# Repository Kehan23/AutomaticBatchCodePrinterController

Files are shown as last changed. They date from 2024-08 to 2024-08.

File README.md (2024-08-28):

# Automatic Batch Code Printer Controller

This repository contains the design and implementation details for the Automatic Batch Code Printer, developed as part of the EN2160 - Electronic Design Realization course at the University of Moratuwa. The project leverages ATmega microcontrollers, shift registers, and other electronic components to achieve precise and reliable printing on various surfaces.

## Table of Contents
- [Introduction](#introduction)
- [Schematics](#schematics)
- [PCB Design and Assembly](#pcb-design-and-assembly)
- [Enclosure Design](#enclosure-design)
- [Detailed Programming Information](#detailed-programming-information)
- [Daily Log Entries](#daily-log-entries)
- [Getting Started](#getting-started)
- [Contributors](#contributors)

## Introduction

The Automatic Batch Code Printer is designed to generate and print batch codes on multiple surfaces with high precision. It integrates several ATmega microcontrollers that handle tasks such as bit pattern generation, signal processing, pressure control, and surface detection, ensuring high-quality and efficient printing.
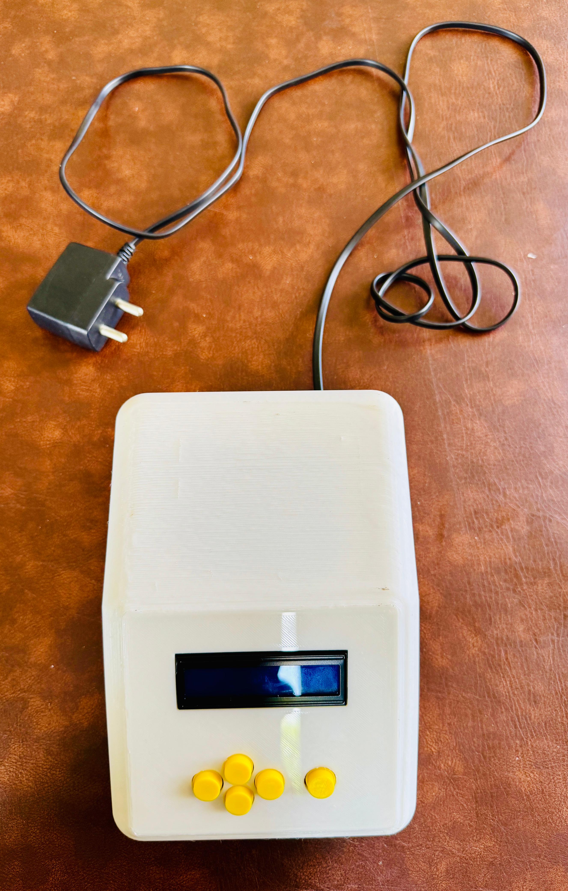
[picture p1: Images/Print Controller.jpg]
Print Controller


### Key Features
- **High Precision Printing**: Utilizes piezoelectric technology and PWM signals for fine control over ink droplet formation.
- **Versatility**: Capable of printing on various surfaces with real-time adjustments for optimal print conditions.
- **Robust and Reliable**: Features fail-safe mechanisms for pressure control and surface detection to prevent printing errors.
- **Efficient and Environmentally Friendly**: Lower energy consumption and minimal ink wastage compared to traditional printing methods.

## Schematics

Detailed schematics for the entire system, including the main and secondary microcontrollers, power supply, shift registers, and pressure control circuits, are provided. These schematics are crucial for understanding the layout and connections between components.
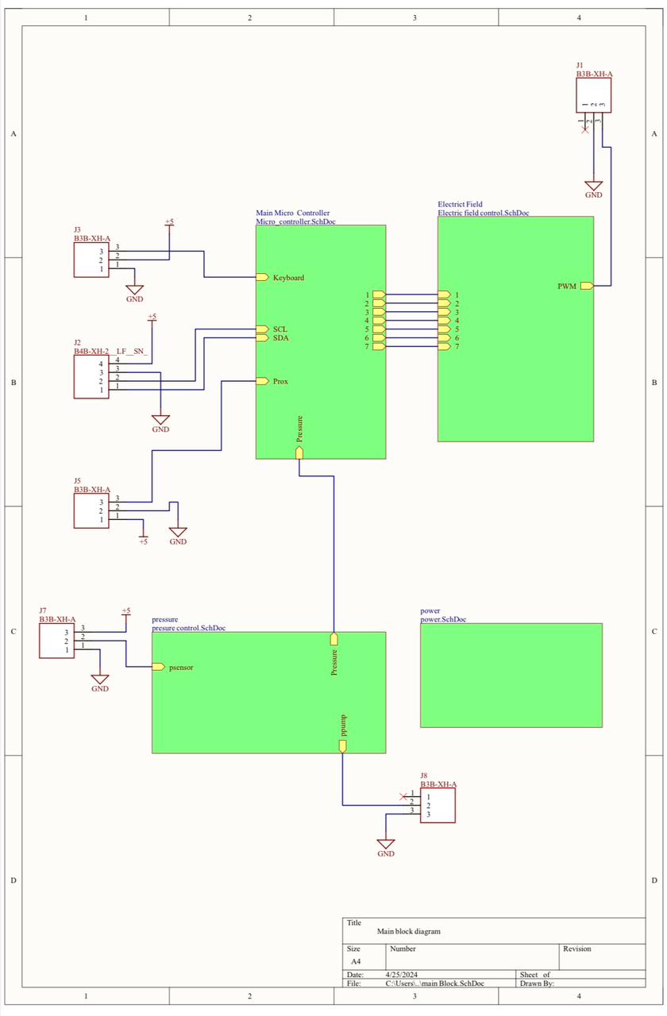
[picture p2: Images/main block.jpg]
Hierarchical Design

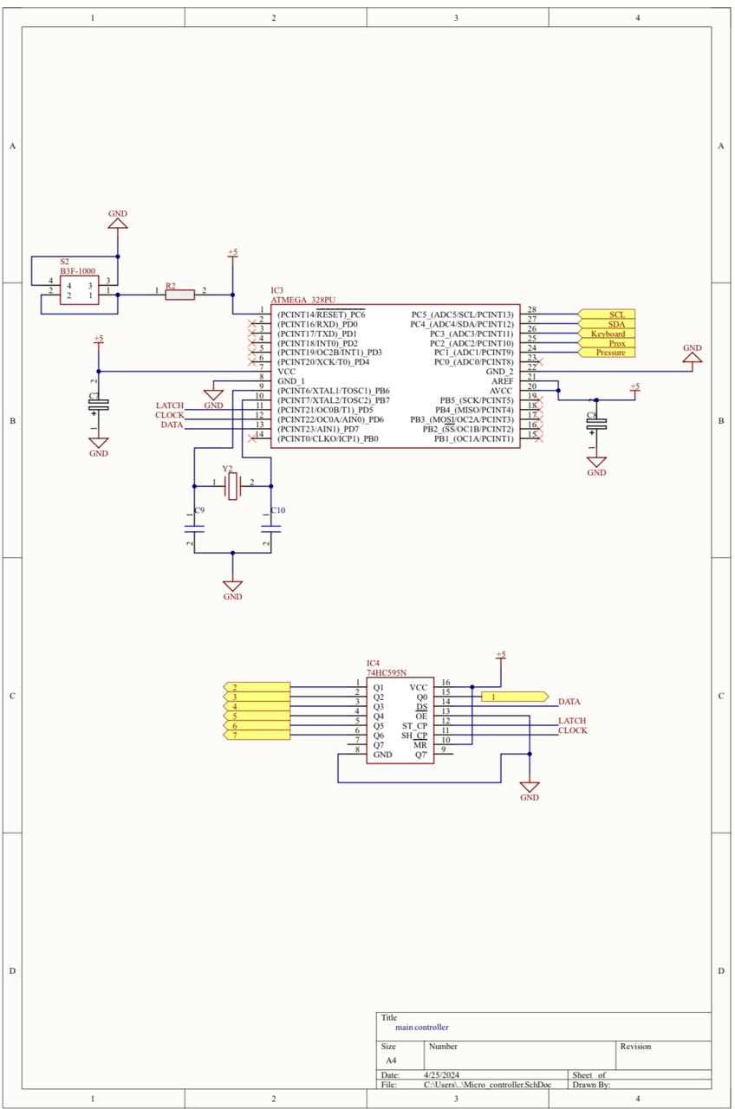
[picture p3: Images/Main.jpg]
Main Circuit

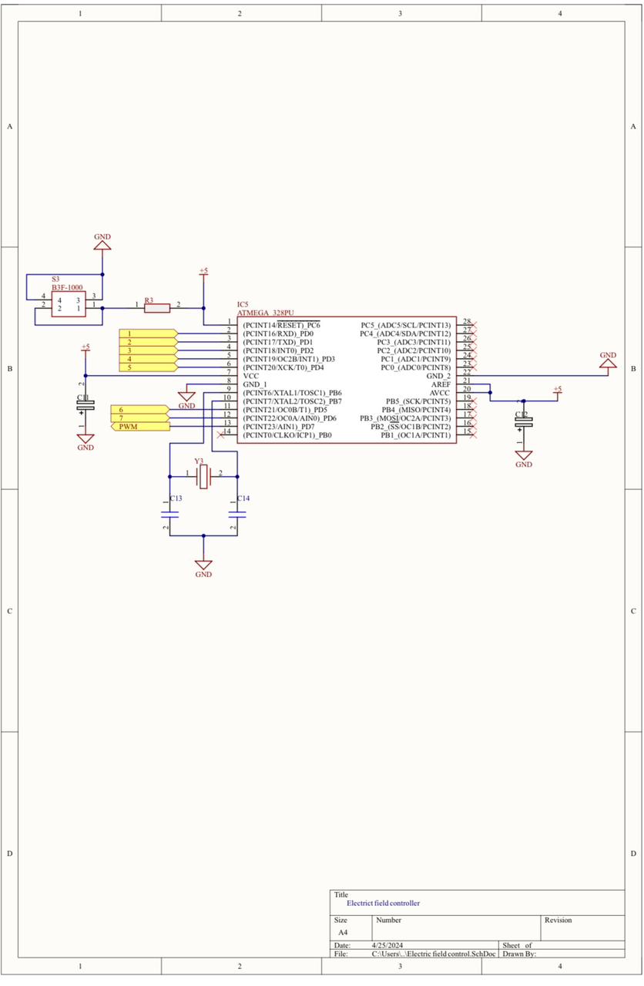
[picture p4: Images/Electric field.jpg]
Electric Field

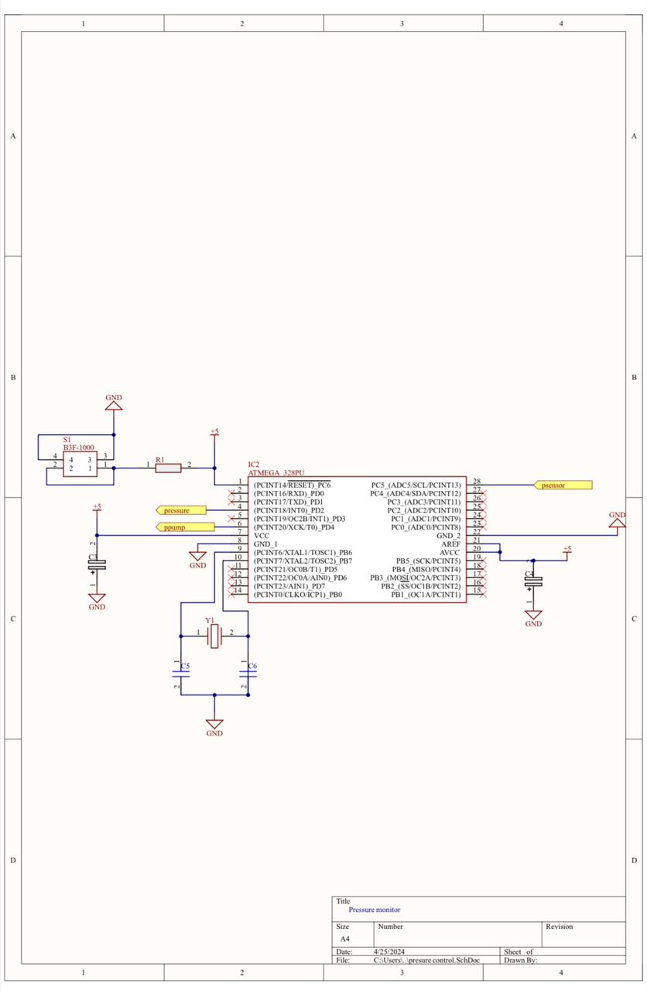
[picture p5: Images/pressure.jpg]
Pressure Controll Design


## PCB Design and Assembly

### PCB Design
The PCB design for this project was meticulously crafted to ensure signal integrity, power management, and minimal interference. The design process included optimal component placement, routing, and adherence to industry standards.
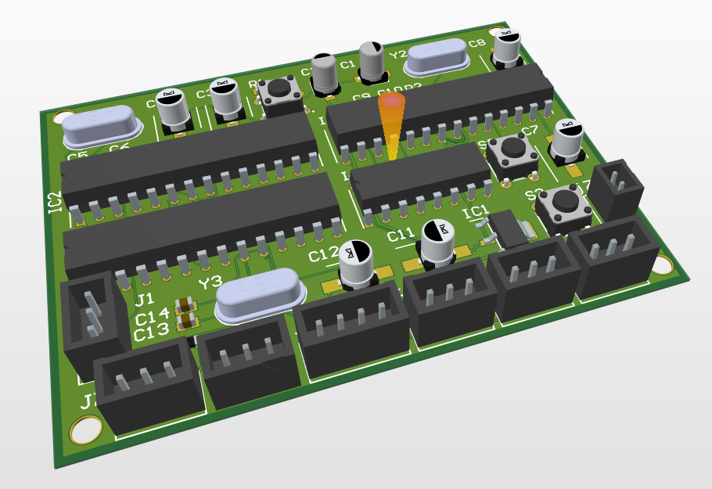
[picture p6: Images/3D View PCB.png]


### PCB Assembly
Photographs of both the bare and soldered PCBs are included, along with evidence of PCB testing to ensure functionality before final assembly.
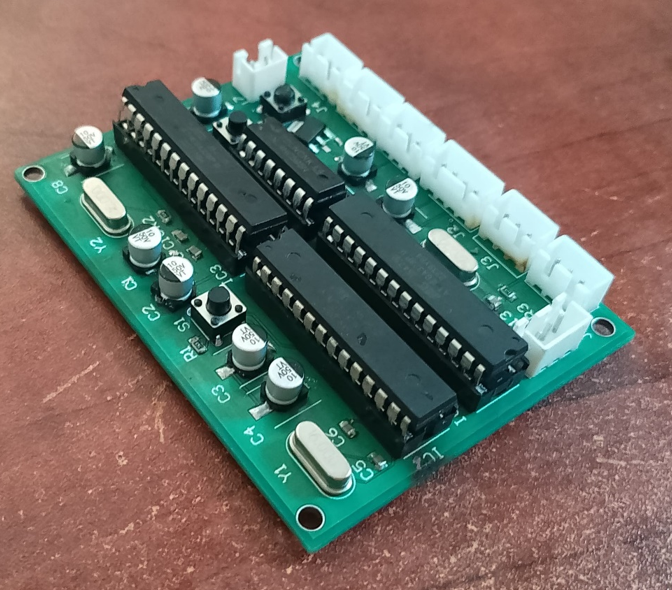
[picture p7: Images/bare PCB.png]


## Enclosure Design

The project also includes a custom-designed enclosure for the batch code printer. The enclosure is designed to house all the critical components securely while providing easy access for maintenance. Detailed design drawings and photographs of the assembled enclosure are available.
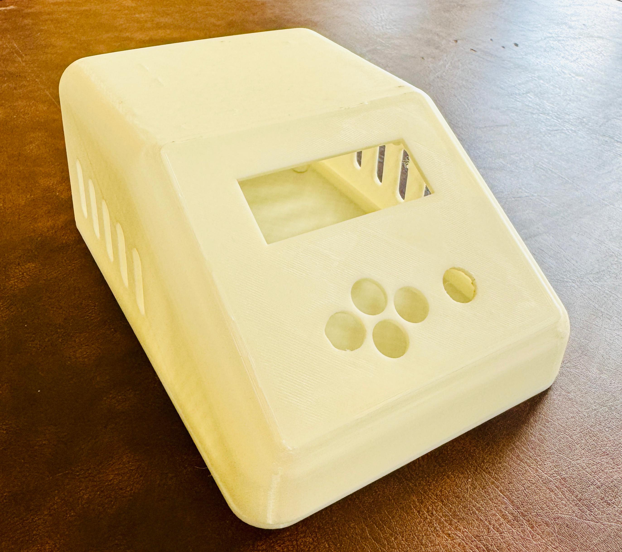
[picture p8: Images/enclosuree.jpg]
Enclosure


## Detailed Programming Information

The programming section includes the full source code used to control the printer, handle user inputs, and manage the printing process. This code is essential for replicating the functionality of the system and includes:
- ASCII to bitmap conversion for dot matrix printing.
- PWM signal generation for controlling the print head.
- Proximity sensor integration for accurate surface detection.
- Pressure monitoring and control algorithms.

## Daily Log Entries

A detailed log of the project development process is provided, documenting each stage from initial concept to final implementation. This includes design reviews, component selection, circuit design, programming, PCB layout, and enclosure fabrication.

## Getting Started

### Prerequisites
- **Arduino IDE**: Required for compiling and uploading the provided code to the microcontrollers.
- **Microchip Studio**: Used for programming the ATmega microcontrollers.

### Instructions
1. **Hardware Setup**: Assemble the circuit and connect all components as per the provided schematics and PCB layout.
2. **Software Upload**: Use the Arduino IDE to upload the code to the microcontrollers.
3. **Operation**: Power up the system, input the desired batch code using the provided keyboard interface, and initiate the printing process.

## Contributors

- **Anjula M.K** 
- **Meemanage N.A**
  
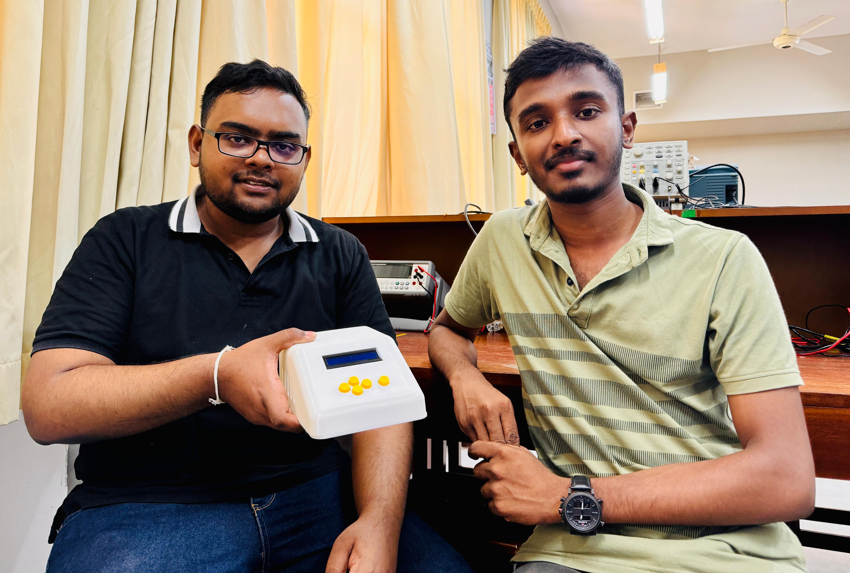
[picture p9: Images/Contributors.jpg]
Group


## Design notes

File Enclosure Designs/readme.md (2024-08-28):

# Enclosure Designs for Print Controller

## Top Part of the Enclosure
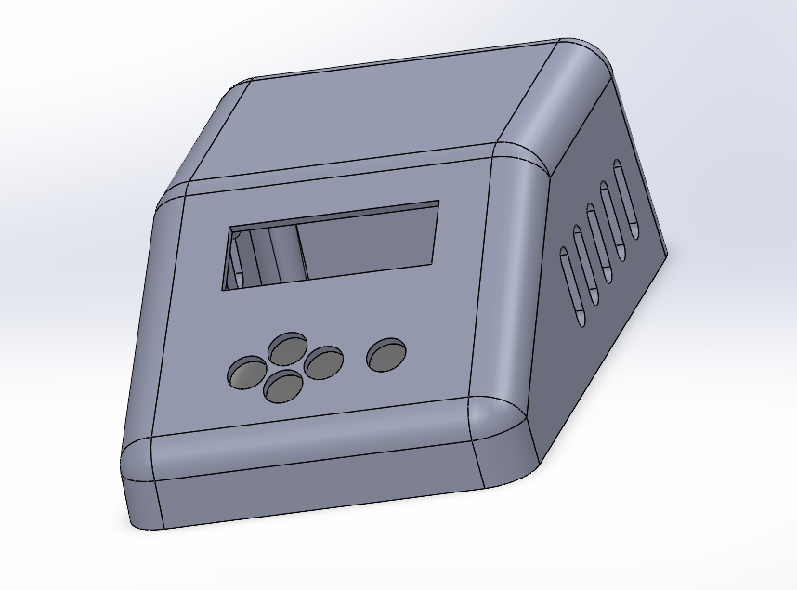
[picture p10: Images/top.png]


## Base of the Enclosure
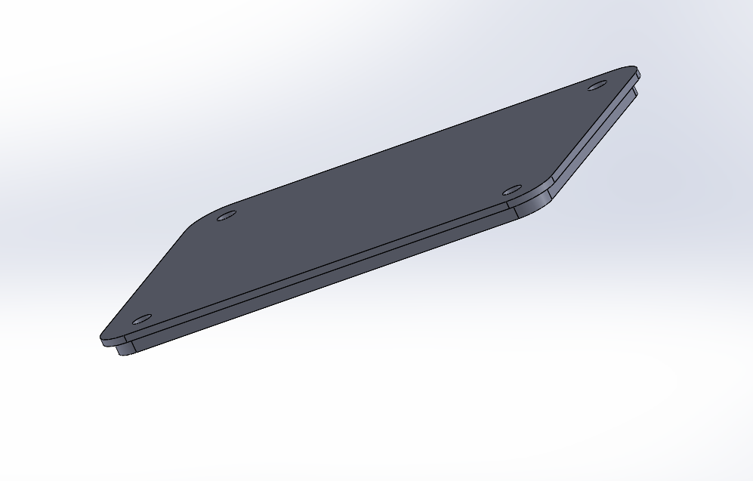
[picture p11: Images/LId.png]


## Printed Enclosure
Printed Enclosure

## Assembly of the Enclosure
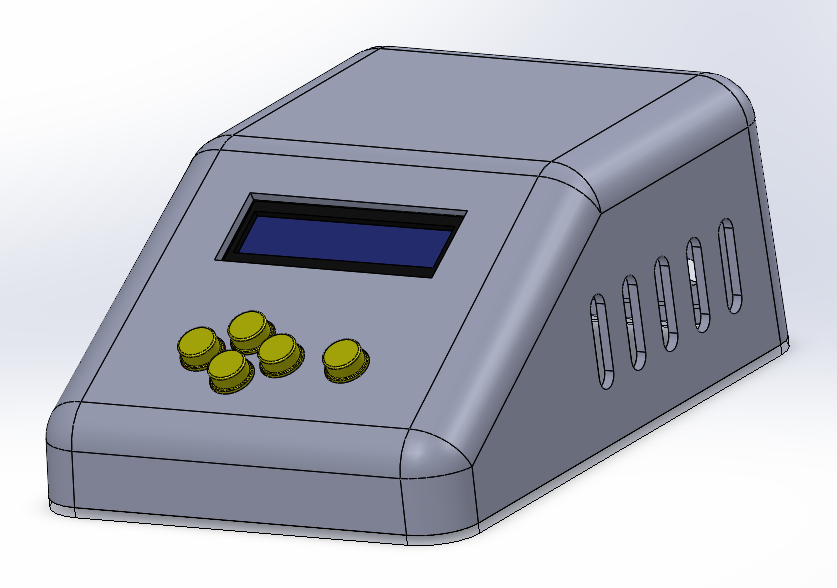
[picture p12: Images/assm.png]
Assembly


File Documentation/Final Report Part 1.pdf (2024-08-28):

## Department of Electronic and Telecommunication Engineering

## University of Moratuwa

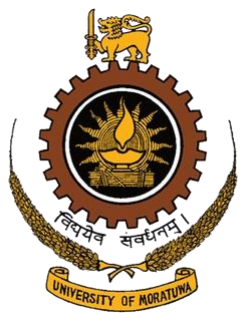
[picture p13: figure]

## EN2160 - Electronic Design Realization Automatic Batch Code Printer

Design Methodology Report

Anjula M.K | 210368V
Meemanage N.A | 210385U

Table of Contents

## 1.Introduction

In today’s fast-paced industrial environment, the ability to efficiently and accurately label products with essential information such as manufacturing dates, expiry dates, and batch numbers is crucial. Automatic batch coding technologies have emerged as a vital component in various sectors, including pharmaceuticals, food and beverage, cosmetics, and electronics. These technologies enhance traceability, compliance, and quality control, ensuring that consumers receive reliable and safe products.

The advancements in automatic batch coding devices, particularly those utilizing inkjet printing technology, represent a significant leap forward in the industry. Inkjet printing technology stands out due to its versatility, speed, and precision, making it an ideal choice for high-volume production environments. This technology can print on a wide range of surfaces and materials, including glass, metal, plastic, and paper, which adds to its applicability across different industries.

Leading companies and universities are at the forefront of innovating and refining these technologies. Their research and development efforts focus on improving the efficiency, accuracy, and environmental sustainability of inkjet printing systems. Innovations include the development of high-resolution printers, the integration of smart technology for real-time monitoring and adjustments, and the use of environmentally friendly inks that reduce the carbon footprint of the printing process.

This report aims to provide a comprehensive overview of the current state of automatic batch coding devices using inkjet printing technology. It will cover the progress made in the field, plan the next steps for future advancements, and map the stakeholders involved in these developments. Additionally, it will observe user requirements, stimulate ideas for further innovation, and present conceptual designs and functional block diagrams. The evaluation criteria for selecting the best solutions, along with detailed considerations for ink and ink tube selection, will also be discussed. Finally, the report will delve into the schematics of selected conceptual designs, PCB design and 3D views, and enclosure design, providing a holistic view of the development and implementation of these cutting-edge technologies.

By examining these aspects, the report seeks to highlight the importance of automatic batch coding technologies and their role in enhancing industrial productivity and product safety. Through collaboration between industry leaders and academic institutions, continuous improvements can be achieved, paving the way for more advanced and sustainable batch coding solutions.

2.Review Progress: Project- Automatic Batch Code printer.

Automatic Batch Code Printing Technologies So far.

Introduction: Automatic batch coding technologies play a crucial role in various industries by enabling efficient and accurate labeling of products with essential information such as manufacturing dates, expiry dates, and batch numbers. This report aims to provide an overview of the advancements and innovations in automatic batch coding devices utilizing inkjet printing technology, with a focus on solutions offered by leading companies and universities.

1. Hitachi Inkjet Printing Solutions: Hitachi offers a range of ink formulations and dynamic models for batch coding applications. Their ink formulations allow codes to adhere to various forms of primary packaging, including paper, PP, PET, HDPE, glass, and metal. Hitachi's dynamic models, such as the UX2, UX Basic Model, UX Dynamic Model, and Twin Nozzle Cartridge Model, provide versatility and reliability in batch coding operations. Additionally, the Hitachi Batch Code Ink Jet Printer PXR-D460W offers mobility and compact design, making it suitable for diverse production environments.
2. Domino Printing Sciences: Domino Printing Sciences provides a comprehensive range of batch coding solutions, including manual, semi-automatic, and automatic systems. Their manual batch coding solutions are suitable for small-scale production runs, while semi-automatic solutions offer electronic-driven operation for larger batches. Domino's automatic batch coding machines integrate seamlessly into production lines, applying codes without operator intervention. The company offers both contact and non-contact batch coding machines, utilizing technologies such as thermal transfer overprinting (TTO), continuous inkjet printing (CIJ), and thermal inkjet printing (TIJ).
3. Linx Printing Technologies: Linx specializes in batch coding technologies designed for high-speed printing onto various types of packaging. Their lot number printers ensure clear and durable batch codes for traceability and compliance with regulatory requirements. Linx's automatic coding machines offer ease of setup and operation, with user-friendly interfaces and smartphone-style touchscreen controls. Their continuous inkjet printer, the Linx 8900, is suitable for harsh production environments with its ingress protection (IP) rating.
4. Research and Innovations: Universities and research institutions have also contributed to advancements in automatic batch coding technologies. Research projects focus on improving printing accuracy, speed, and versatility while exploring novel ink formulations and printing methods.

Below is a short, summarized report regarding a research paper published in Linkedin.com

This research paper explores various aspects of batch coding technology, focusing on the importance, types, operation, and application of batch coding machines, particularly in the context of inkjet printing. The paper emphasizes the significance of high-quality batch coding in ensuring product traceability, compliance with regulations, and brand reputation in industries such as FMCG, pharmaceuticals, and automotive.

Key Findings:

1. Importance of Batch Coding: Batch codes play a crucial role in product traceability, allowing manufacturers to track products throughout the supply chain and facilitate efficient recalls if necessary. They contain vital information about manufacturing dates, expiry dates, and other relevant details.
2. Types of Batch Coding Machines: The paper identifies three main types of batch coding machines: manual handheld, semi-automatic, and automatic. Each type caters to different production needs, with automatic systems being the preferred choice for large-scale manufacturing.
3. Technology Overview: Various technologies are available for batch coding, including thermal transfer overprinting (TTO), thermal inkjet (TIJ), continuous inkjet (CIJ), laser marking, and large character marking (LCM). Each technology offers distinct advantages in terms of printing quality, speed, and suitability for different substrates.
4. Operation of Inkjet Batch Coding Machines: Inkjet batch coding machines are user-friendly and offer flexibility in customization. Operators can easily set up the machines to print alphanumeric characters, barcodes, and other information according to specific requirements.
5. Application Examples: The paper provides insights into the application of batch coding machines in different packaging formats, such as plastic bags, bottles, jars, and cartons. It highlights the importance of selecting the appropriate coding technology based on packaging features and production line requirements.

## 3.Plan Next Steps

After outlining the objectives and methodology for the development of an automatic batch coding system utilizing inkjet printing technology, the next crucial step is to plan the subsequent actions to ensure the successful execution of the project. This report presents a comprehensive plan for the next steps based on the outlined project proposal.

### 1. Review Project Scope and Objectives

- Conduct a thorough review of the project scope and objectives to ensure alignment with stakeholders' expectations and industry requirements.
- Verify that all necessary components and functionalities are adequately addressed in the project plan.

### 2. Establish Timeline and Milestones

- Develop a detailed timeline with specific milestones for each phase of the project, including design, fabrication, programming, testing, documentation, and support.
- Assign responsibilities to team members and establish deadlines for each milestone to maintain accountability and track progress effectively.

### 3. Procurement and Material Acquisition:

- Identify and procure all necessary materials, components, and equipment required for the fabrication of the custom print head, microcontroller programming, enclosure construction, and ink selection.
- Ensure that materials meet quality standards and specifications outlined in the project requirements.

### 4. Design and Fabrication of Print Head

- Initiate the design and fabrication process for the custom print head, considering factors such as nozzle size, heating element placement, and ink delivery mechanisms.
- Conduct prototype testing to validate design specifications and functionality before proceeding to full-scale fabrication.

### 5. Microcontroller Programming

- Begin the development of control algorithms and software to interface with the print head and manage printing operations.
- Program the ATmega328P microcontroller to receive batch information from the user interface and command the print head accordingly.

### 6. Enclosure Design and Construction:

- Commence the design phase for the enclosure, ensuring compatibility with the system components and providing accessibility for maintenance.
- Fabricate the enclosure using appropriate materials and assembly techniques to ensure protection and ease of use.

### 7. Integration and Testing:

- Assemble the system components within the enclosure and perform rigorous testing to validate functionality, reliability, and print quality.
- Iterate on design and software as necessary based on testing results to optimize performance and address any identified issues.

### 8. Documentation and Support:

- Create comprehensive documentation, including assembly instructions, operating procedures, and troubleshooting guidelines, concurrently with system development.
- Provide ongoing support and assistance to users for successful implementation and operation of the automatic batch coding system.

### 9. Stakeholder Communication and Feedback:

- Maintain regular communication with stakeholders to provide updates on project progress, address any concerns or feedback, and ensure alignment with expectations.
- Solicit feedback from stakeholders throughout the project lifecycle to incorporate any necessary adjustments or refinements

## 4.Stake Holder Mapping

The list of stakeholders that are related to our project is given below.

1. Project Team Members:
2. Project Supervisor
3. End-Users/ Customers
4. Regulatory Bodies (Government)
5. Industry Associations (Packaging and manufacturing industry)
6. Financial Stakeholders
7. Marketing and Sales
8. Environmental and Sustainability Groups:
9. Community
10. Competitors (Competing companies in the same industry)
11. Research and Development
12. Media (News outlets covering advancements in manufacturing or technology)

## 5.Observe Users

1. User Interface Preferences:
- Users expressed a preference for a simple and intuitive user interface that allows for easy input of batch information.
- Clear and legible display screens were highlighted as important for readability in busy production environments.
2. Print Head Interaction:
- Operators emphasized the importance of a reliable and durable print head that requires minimal maintenance.
- Ease of access to the print head for cleaning and replacement of ink cartridges was identified as a key consideration.
3. Enclosure Design:
- Observations revealed a need for an enclosure that provides adequate protection for the internal components while allowing for easy access during maintenance and troubleshooting.
4. Documentation and Support:
- Stakeholders highlighted the importance of comprehensive documentation and support materials to assist with assembly, operation, and troubleshooting of the automatic batch coding system.
- User training programs and ongoing technical support were identified as essential for successful implementation and operation of the system.

## 6.User Requirements

Introduction: Inkjet printing technology has emerged as a versatile tool with diverse applications, ranging from graphical patterning to precise material deposition in various industries. As we embark on the journey of developing an inkjet printer tailored for batch coding purposes, it is imperative to understand the specific user requirements associated with this technology. This report aims to outline these requirements comprehensively, facilitating the creation of conceptual designs that effectively address user needs.

Batch code printing is widely utilized across various industries for product identification, tracking, and compliance purposes. Some industrial uses of batch code printing include:

- Pharmaceutical: Ensure traceability and regulatory compliance throughout the supply chain.
- Food and Beverage: Track inventory, monitor product freshness, and facilitate recalls.
- Cosmetics and Personal Care: Track formulations, expiration dates, and ensure regulatory compliance.
- Automotive: Label parts for identification, quality control, and traceability in manufacturing.
- Electronics: Label components for inventory management, quality control, and defect identification.
- Chemical: Label products for tracking, regulatory compliance, and safety standards.

6.1User requirements from Inkjet batch code printing.

1. Accuracy and should be precise.

Users demand high precision and accuracy in batch coding to ensure legibility and compliance with stringent regulatory standards. The ability to consistently produce clear and error-free batch codes is critical for product identification, traceability, and quality control purposes. Whether the substrate is flat or irregular, the inkjet printer must be capable of depositing ink with precision, ensuring that each batch code is accurately applied regardless of surface variations. This level of accuracy is essential to prevent misidentification, minimize errors in product tracking, and uphold regulatory compliance requirements across

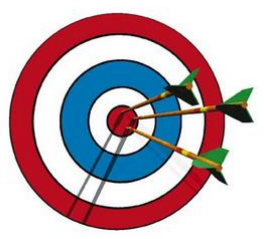
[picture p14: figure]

industries. Therefore, the inkjet printer's capability to maintain precision and accuracy, even under challenging printing conditions, is paramount to meet the exacting demands of users in various manufacturing environments.

2. Speed and efficiency in batch coding.

Efficient batch coding necessitates fast printing speeds to minimize production downtime and meet the demands of high-volume manufacturing environments. Users expect the inkjet printer to offer rapid printing capabilities without sacrificing quality, ensuring that batch codes are

applied swiftly and accurately to keep pace with production schedules. The ability to achieve high-speed printing while maintaining precision and legibility is crucial for streamlining manufacturing processes and maximizing productivity. Furthermore, fast printing speeds enable manufacturers to meet tight deadlines, respond quickly to market demands, and optimize operational efficiency. Therefore, the inkjet printer must deliver rapid printing performance to meet user expectations for timely batch code application and ensure seamless integration into production workflows.

### 3. Cost effectiveness over other printing technologies

Cost considerations play a crucial role in industrial operations, requiring a delicate balance between performance and affordability. Users are keen to invest in an inkjet printer solution that offers cost-effective batch coding solutions, allowing them to minimize operational expenses while maximizing productivity. This entails not only the initial investment in the printer hardware but also ongoing

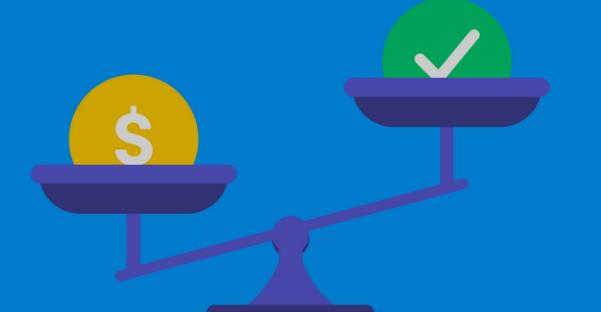
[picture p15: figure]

costs such as ink consumption, maintenance, and operational efficiency. Users expect the inkjet printer to provide a favorable return on investment by delivering reliable performance at a competitive price point. Therefore, affordability is a key factor that influences user preferences when selecting an inkjet printer for batch coding applications. Additionally, cost-effective solutions enable businesses to remain competitive in the market while maintaining profitability and sustainability in their operations.

### 4. Reliability and Maintenance

Continuous operation is vital for industrial applications, highlighting the need for a reliable inkjet printing solution with minimal downtime. Users demand an inkjet printer that can sustain continuous operation over extended periods without encountering frequent malfunctions or breakdowns. This requires robust hardware components, advanced technology, and efficient ink delivery systems that can withstand the rigors of industrial production environments.In addition to reliability, users also emphasize the importance of ease of maintenance for the inkjet printer. They expect the printer to have accessible components and straightforward troubleshooting procedures, enabling

maintenance personnel to quickly diagnose and resolve any issues that may arise. This minimizes downtime associated with maintenance tasks and ensures that production schedules remain on track.Furthermore, users value proactive support and timely assistance from the printer manufacturer or service provider. Access to technical support, spare parts availability, and comprehensive maintenance contracts are essential considerations for users when selecting an inkjet printing solution.

Understanding user requirements is paramount in the development of an inkjet printer tailored for batch coding applications. By addressing the precision, speed, versatility, cost-effectiveness, integration, reliability, and maintenance aspects outlined above, we can create conceptual designs that meet the diverse needs of users across various industries. These designs will pave the way for the development of a robust inkjet printing solution that sets new standards in batch coding efficiency and effectiveness.

## 7.Stimulating Ideas:

Following the thorough analysis of user requirements for automatic batch coding, the next crucial step in the project lifecycle is to stimulate innovative ideas that will inform the conceptual designs of the system. This phase serves as a creative brainstorming session aimed at exploring potential solutions, technologies, and approaches to address the identified user needs and industry challenges. By fostering a collaborative and forward-thinking environment, the team can generate novel ideas that push the boundaries of conventional batch coding practices and pave the way for groundbreaking innovations in the field.

1. Advanced Printing Technologies:

In our pursuit of enhancing batch coding efficiency, we're exploring cutting-edge printing technologies like inkjet, laser, and thermal printing. These methods offer high-speed and high-resolution capabilities, promising clear, legible, and compliant batch codes. We're also integrating machine vision systems and AI algorithms for real-time quality control,

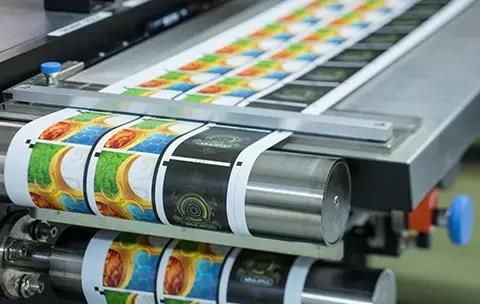
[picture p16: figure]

ensuring error detection and rectification during printing. Through this innovative approach, we aim to set new standards of excellence in batch coding across industries.

2. Intelligent Ink Formulations:

Developing custom ink formulations designed for specific substrates and environmental conditions, prioritizing optimal adhesion, durability, and readability of batch codes. Additionally, our research focuses on eco-friendly and sustainable ink options, aiming to minimize environmental impact without compromising printing performance or quality. Through these efforts, we're committed to delivering efficient and environmentally responsible batch coding solutions.

3. Smart Packaging Technologies:

Delving into smart packaging solutions like RFID tags and QR codes to enhance batch coding efforts, adding layers of product identification and authentication. Additionally, exploring IoT sensor integration to enable real-time monitoring and management of batch-coded products during transit and storage. These advancements promise enhanced traceability and security throughout the supply chain, bolstering product integrity and consumer confidence.

4. Customization and Personalization:

Diving into batch coding customization and personalization to cater to diverse branding and labeling needs across industries and product categories. Additionally, we're exploring variable data printing technologies to facilitate on-demand batch coding of serialized or individually labeled products. These initiatives aim to provide flexible and tailored solutions, empowering businesses to meet specific regulatory and consumer demands with ease and efficiency.

5. Regulatory Compliance and Security:

Focused on implementing robust security features and anti-counterfeiting measures to safeguard batch codes against unauthorized tampering or replication, ensuring adherence to regulatory standards. Additionally, we're exploring the potential of blockchain technology and distributed ledger systems to enable immutable tracking and authentication of batch-coded products across their lifecycle. These efforts aim to enhance transparency, traceability, and trust in the supply chain while mitigating the risks associated with counterfeit products.

6. Collaborative Partnerships and Industry Collaboration:

Fostering collaborative partnerships with
key industry stakeholders, including
manufacturers, suppliers, regulatory agencies, and technology providers, to leverage collective expertise and resources in advancing batch coding practices.
Additionally, we're exploring opportunities
for cross-disciplinary collaboration and

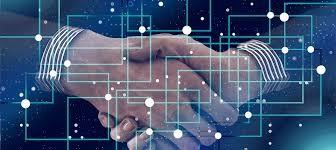
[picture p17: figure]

knowledge sharing to accelerate innovation and drive continuous improvement in automatic batch coding technologies. These collaborative efforts aim to enhance industry standards, promote best practices, and deliver cutting-edge solutions that meet the evolving needs of our customers and the broader market.

8.Conceptual Designs.

Introduction
An automatic batch coding device is designed to streamline the process of marking or labeling batches of products in manufacturing or warehouse environments. It typically functions by automatically applying codes, such as batch numbers, expiration dates, or other relevant information, onto the packaging or products themselves. This is achieved through precise control mechanisms that ensure accurate placement and legibility of the codes. Additionally, these devices may integrate with software systems to manage batch data and synchronize with production lines, enabling efficient tracking and traceability throughout the supply chain.

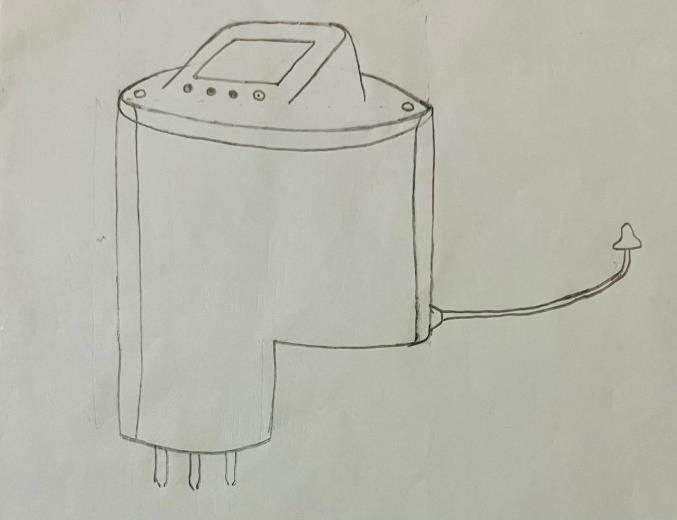
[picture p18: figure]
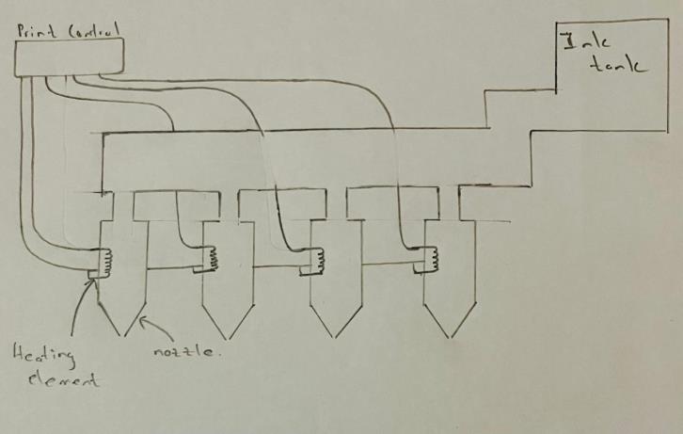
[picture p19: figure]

### 8.1 Conceptual Design 1

Concept for enclosure

In the first conceptual design, we leverage heating elements integrated within each individual nozzle to create a localized pressure differential relative to atmospheric pressure upon receiving a signal from the print control system. Each nozzle is equipped with its own dedicated heating element, comprising a coil-like structure embedded within the nozzle assembly during fabrication.

To ensure a continuous ink supply to the nozzles, a centralized ink tank is employed, serving as the primary reservoir for ink distribution. This centralized ink tank facilitates seamless and uninterrupted ink flow to each nozzle, optimizing printing performance and efficiency.

By utilizing heating elements and a centralized ink distribution system, this conceptual design offers precise control over ink ejection and distribution, resulting in enhanced print quality and consistency. Moreover, the individual heating elements enable independent operation of each nozzle, allowing for greater flexibility and customization in batch code printing applications.

While the first conceptual design offers certain advantages, there are notable inefficiencies that warrant consideration.

Firstly, the design's reliance on individual heating elements for each nozzle results in elevated power consumption. The continuous supply of power to numerous heating elements contributes to higher energy usage, posing challenges in terms of operational costs and environmental sustainability.

Secondly, the design's heating elements face difficulties in rapid cooling after ejecting ink droplets. Due to the lingering heat within the heating elements, ink flow may persist beyond the intended duration, potentially leading to inaccuracies or inconsistencies in batch code printing. This prolonged heat retention impedes efficient ink ejection and overall printing performance, detracting from the design's effectiveness and reliability.

Those two reasons are also proved by following calculations.

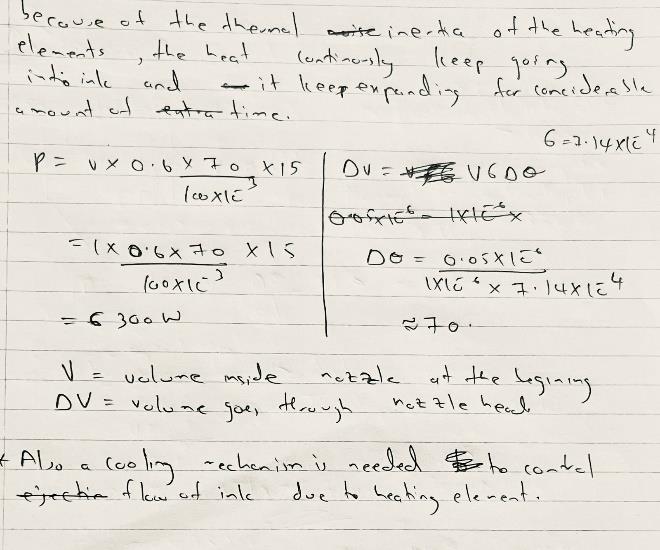
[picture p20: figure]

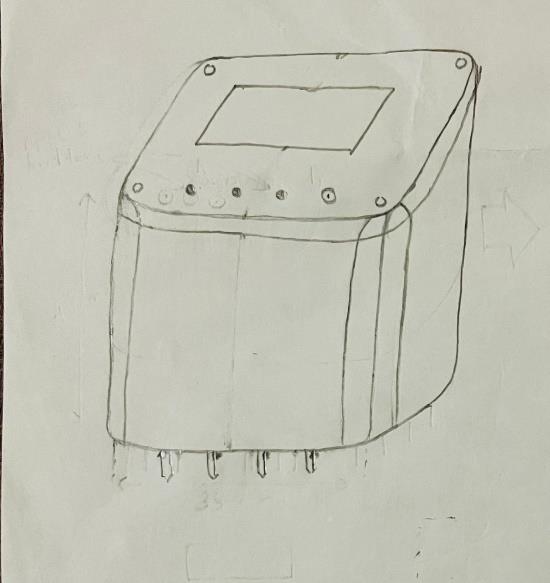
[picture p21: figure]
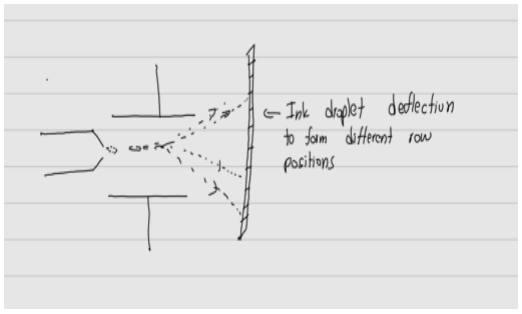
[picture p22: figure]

### 8.2 Conceptual Design 2

Concept for enclosure design

In the second conceptual design, a distinct approach is adopted to address the inefficiencies encountered in the first design iteration. Rather than employing individual heating elements, this design integrates individual valves for nozzles and a pressure inkjet system for the nozzle array with a electric field generator to deflect the ink jet path.

Upon receiving a signal from the control circuit the designated nozzle valve opens as the pressure of the ink pressure chamber is high the ink rushes outside of the nozzle. The pressure of the pressure chamber will be controlled for optimum ink ejection as ink bubbles. Then when the ink droplet does through the electric field it gets charged and get deflected. By deflecting these ink droplets we can print different rows using one nozzle array without using multiple nozzle arrays.

This enhanced control capability facilitates precise regulation of ink flow, enabling accurate batch code printing while mitigating potential issues associated with ink over-dispersion. Additionally, by eliminating the need for individual heating elements, this design reduces power consumption and, thereby offering a more sustainable and cost-effective solution for batch code printing applications.

Furthermore, the second conceptual design boasts reduced power consumption compared to its predecessor, the first design iteration. By eschewing individual heating elements for pressure and electric field control systems this design significantly lowers the overall power requirements. This not only contributes to operational cost savings but also aligns with sustainability goals by minimizing energy consumption. This will be proved by the below calculations.

However, a notable drawback of this approach is the its high design complexity the controls need to calculate the electric field strength and adjust it accordingly. These calculations need to have high precision as the gap bet ween the dotted rows are small. And we need ti implement different controls for pressure management also.

### 8.3 Conceptual Design 3

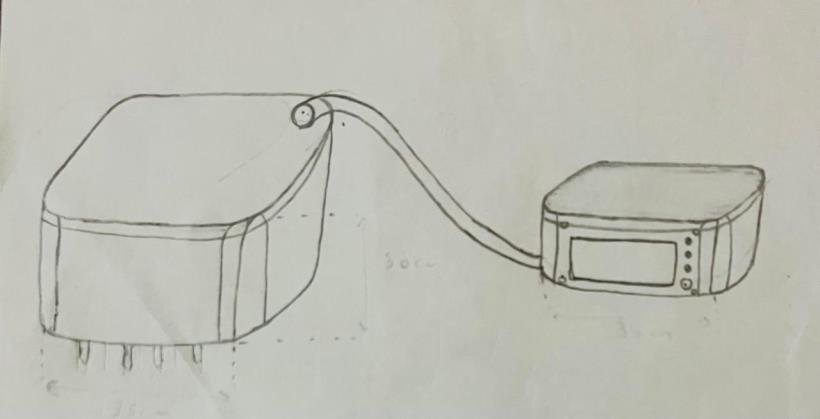
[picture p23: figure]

Concept for enclosure design

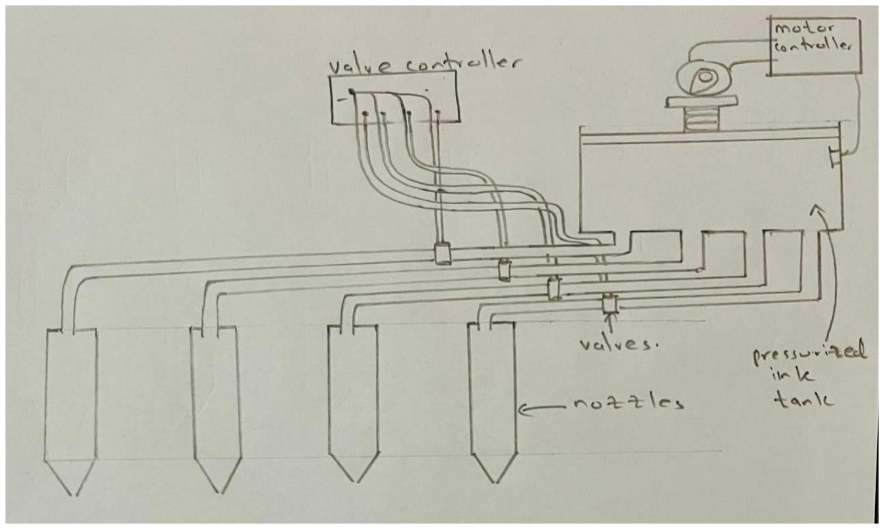
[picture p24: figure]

The third conceptual design incorporates a centralized pressure ink tank and individually controlled electronic solenoid ink valves, representing a sophisticated approach to batch code printing. Each ink valve is meticulously activated by a signal from the control circuit through a relay switch, enabling precise regulation of ink flow. Upon activation, the corresponding ink valve promptly opens, facilitating the seamless transfer of ink from the centralized pressure chamber to the nozzle chamber. This equilibrium of pressure within the nozzle chamber ensures controlled ink ejection, resulting in the precise deposition of ink droplets through the nozzle.

One of the notable advantages of this design is its versatility in arranging the nozzles in a clustered configuration, promoting clarity and legibility in the printed letters. By dispensing ink droplets in close proximity, the clustered arrangement enhances the visibility and distinction of the printed content. Additionally, the centralized approach eliminates the need for separate ink ejection mechanisms for each nozzle, streamlining the ink delivery process and bolstering overall efficiency and reliability in batch code printing applications.

One disadvantage of this method is the potential complexity and maintenance requirements associated with the centralized pressure ink tank and individually controlled electronic solenoid ink valves. Moreover, the centralized approach may necessitate regular calibration and adjustment to ensure uniform ink flow and consistent printing performance across all nozzles, adding to maintenance overhead and operational complexity.

## 9.Functional Block Diagram

### 9.1 Design 1

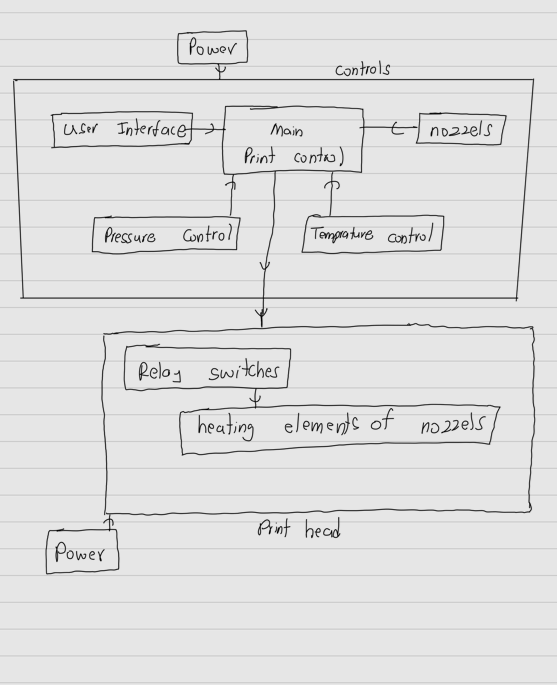
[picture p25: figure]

The functional block diagram begins with the power circuit, serving as the foundational element to provide the necessary electrical energy for the entire system. Following this, the control circuit takes precedence, featuring a programmable matrix responsible for orchestrating the printing process. This matrix is meticulously programmed to execute the desired letter sequences along with associated numerical data, ensuring precise and accurate batch code generation.

Adjacent to the control circuit lies the temperature and print controller, a pivotal component equipped with relay switches tailored to regulate each individual nozzle. This controller acts as the intermediary between the control circuit and the printing mechanism, facilitating seamless communication and coordination. Additionally, integrated temperature sensors further enhance functionality by monitoring and maintaining optimal operating conditions, ensuring consistent performance and reliability throughout the printing process

### 9.2 Design 2

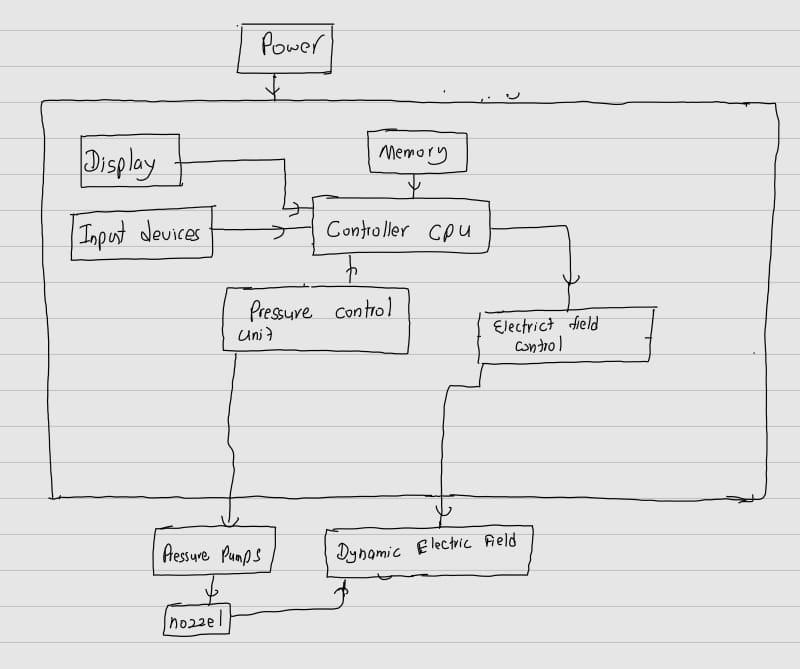
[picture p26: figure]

Input Device is where the code to be printed is entered. This could be a computer a keyboard, or a storage device such as a USB drive. Then the Controller CPU formats the data and sends it to the printer. Memory stores the code to be printed. Display shows the user the status of the printer, such as the current job or any errors. Then it makes the 2d dot matrix and send it to the Engine CPU which controls the printing mechanism. Proximity Sensor detects the presence of media (like labels or tags) and ensures the printer is ready to print. Pressure Control This unit regulates the amount of ink used during printing. Engine CPU monitor both of these processors and give necessary signals to Relay Switches which controls nozzle valves which control the flow of ink to the print nozzles.

Nozzles and Metal Plates: These are the components that create the printed image on the media. An essential feature of the motor controller circuit is its integration with pressure sensors, which are intricately linked to the nozzles. These sensors serve to monitor the pressure levels within the nozzles, providing crucial feedback to the motor controller circuit to ensure optimal performance and ink ejection consistency. Notably, the motors are strategically mounted atop the nozzles, directly interfacing with pressure chambers to facilitate efficient ink delivery.

### 9.3 Design 3

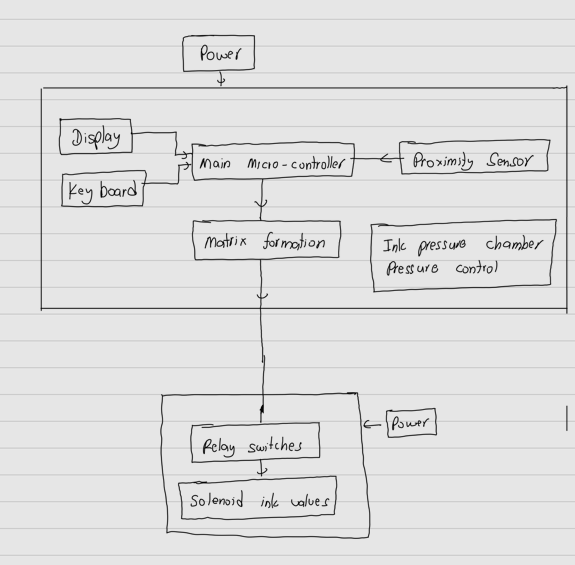
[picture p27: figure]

The third functional block diagram initiates with the power circuit, serving as the foundational element responsible for supplying electrical power throughout the system. Subsequently, the control circuit assumes control, housing a meticulously programmed matrix tailored to execute the desired letter sequences and numerical data required for batch code generation.

Following the control circuit, the signal is seamlessly transmitted to a specialized circuit equipped with relay switches. We can see a centralized pressure tank in this block diagram, which serves as the focal point for ink distribution. Each nozzle is intricately connected to this tank via rubber tubes, establishing a network for efficient ink delivery.

Within this arrangement, electronically controlled solenoid ink valves are strategically positioned along the tubing, precisely regulating ink flow to each nozzle. These valves operate in tandem with the relay switches, ensuring synchronized control and seamless ink distribution across the printing array.

Integral to the functionality of this system is the incorporation of pressure sensors, meticulously attached to the centralized pressure tank. These sensors play a pivotal role in monitoring pressure levels within the tank, providing vital feedback to optimize ink distribution and maintain operational consistency.

## 10.Evaluation Criteria

Enclosure Design Criteria:

1. Functionality: How well the design supports the main functionalities?
2. Aesthetics: How much eye catching and overall appeal of the user?
3. Heat dissipation: How much heat is generated and how well it has been managed?
4. Assembly and serviceability: How easily does the assembly and disassembly is done?
5. Ergonomics: How well does the design fit in the user's hand and allow easy interaction?
6. Durability: How well does the design withstand impacts and environmental conditions?
7. Simplicity

Functional block diagram criteria:

1. Functionality: How well the circuit design meets functional requirements?
2. Manufacturing feasibility: Evaluate the feasibility of manufacturing the design
3. Cost: Evaluate the overall cost effectiveness for the provided functionality
4. Print quality: Evaluate print quality, resolution ?
5. Future proofing: To what extent does the design allow for easy replacement or upgrade of individual components?
6. Power Efficiency : How effectively does the device manage power consumption?

## 11.Selection Matrix

## Selected Design

According to the above results Design 2, which was implemented considering user input, has got 58 marks out of 100 (10 marks per each criteria and there are 13 criterias). Therefore the selected design is design 2.

| Criteria | Design 1 | Design 2 | Design 3
Enclosure design criteria | Functionality | 6 | 5 | 7
| Aesthetics | 6 | 6 | 6
| Heat Dissipation | 2 | 6 | 6
| Assembly And Serviceability | 6 | 5 | 4
| Ergonomics | 6 | 6 | 4
| Durability and Reliability | 4 | 7 | 6
| Simplicity | 6 | 3 | 7
Functional block diagram criteria | Functionality | 5 | 7 | 4
| Feasibility | 3 | 7 | 6
| Cost | 3 | 6 | 4
| Print quality | 5 | 7 | 4
| Future Proofing | 4 | 5 | 7
| Power Efficiency | 2 | 6 | 6
| Total | 45 | 58 | 55

## 12.Ink Selection for printing

The realm of product coding encompasses a wide array of solutions tailored to diverse applications. Factors such as substrate selection, processing setups, line configurations, environmental conditions within the facility, and other variables all exert influence on the efficacy of an ink formula in generating clear, high-quality codes. This multifaceted landscape demands careful consideration to ensure that the chosen solution aligns with the specific requirements of the application, avoiding the risk of producing illegible or distorted codes.

Basically two types of inks that are being currently used in the industry for inkjet printing.
They are,
1. Dye based ink
2. Pigment based ink

1.Dye based ink
Dye-based ink comprises colorants dissolved in a liquid medium, typically water or glycol. This formulation facilitates smooth flow from the printer head to the page and promotes rapid drying upon contact. Commonly employed in standard inkjet printers due to its cost-effectiveness, dye-based ink offers crisp text rendering and produces vivid, vibrant colors in printed images. However, it is important to note that dye-based inks lack waterproof properties and may experience fading over time, with color retention typically lasting between 5 to 25 years.

2.Pigment based ink
Pigmented ink is formulated specifically to produce durable, high-quality color prints suited for professional applications. Unlike standard dye-based ink sets, pigment ink sets offer a broader spectrum of tones, tailored to complement various types of paper. This specialized ink provides professional photographers with enhanced flexibility to enhance color depth, sharpness, and tone through experimentation with different ink and paper combinations. While manufacturers often optimize their ink and paper products for specific pairings, high-end photo printers typically feature both matte black and glossy black options to achieve optimal results across different media types.
Why Dye based ink preferred over pigment based ink in batch code printing?

Dye-based ink is often preferred over pigment-based ink for batch code printing due to several factors. Firstly, dye ink cartridges are typically more cost-effective compared to pigment ink cartridges, as the latter can be priced two to three times higher due to raw material costs.

Additionally, pigment inks require periodic circulation to prevent clumping, particularly in thermal inkjet (TIJ) printers. While pigment continuous inkjet (CIJ) printers automate this process, TIJ printers necessitate manual shaking of the cartridge after periods of inactivity to maintain ink consistency.

Moreover, pigment inks may not offer the same brightness as dye inks, as the larger pigment particles scatter light differently. However, black pigment ink tends to produce darker and more opaque results compared to dye ink, which can be advantageous for certain applications.Overall, dye inks provide softer and more vibrant colors, particularly on light-colored substrates, due to their smaller colorant particles. Additionally, dye inks generally offer quicker drying times, which is beneficial for efficient production line printing.

Furthermore, pigment ink is often deemed more suitable for industrial or heavy-duty outdoor printing applications, while dye ink is predominantly utilized for text-based documents or indoor printing.

Both dye and pigment inks maintain high-quality output, yet dye-based inks tend to produce more

vivid and colorful prints compared to pigment-based inks. Dye-based inks offer a wider color gamut, enhancing the overall quality and performance of printed materials. Particularly, dye-based inks excel in text-based creations and produce sharper prints, with black text appearing notably crisper and darker compared to pigmented ink.

So, by considering above facts Dye based ink is more preferable over pigment based ink for the final objective of the ongoing project.

Compositions of several types of dye-based inks.

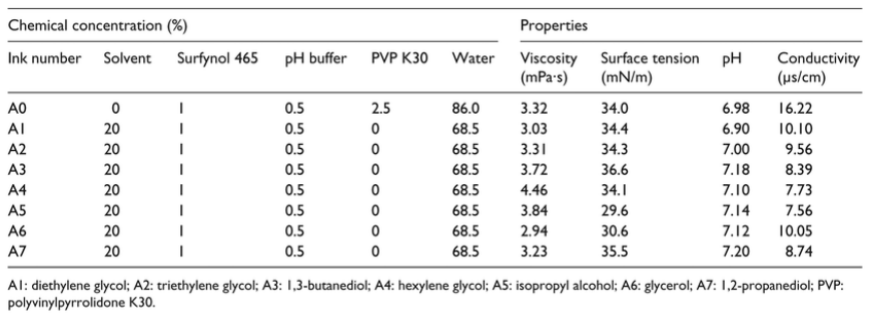
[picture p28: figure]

## 13.Ink Tube Selection

When selecting a tube for inkjet printers, its importance cannot be overstated, as it serves as a crucial component in ink transportation, directly impacting ink quality and printing precision. A high-quality tube is essential to meet the diverse requirements of various applications and ink types.

Key attributes of an ideal tube include exceptional solvent resistance, effective gas barrier properties, minimal moisture permeability, flexibility, smooth outer surface for enhanced sliding properties and flame retardancy.

Maintaining high solvent resistance ensures that the tube can withstand exposure to various ink formulations without degradation, preserving ink quality and preventing clogging or inkjet ejection failures. Effective gas barrier properties prevent oxygen ingress, which can

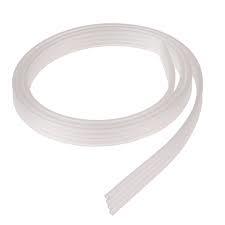
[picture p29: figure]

alter ink composition and lead to ink instability or bubble formation, adversely affecting print quality.

Likewise, minimizing moisture permeability is crucial to prevent moisture intrusion into the ink, which can also compromise print quality and lead to malfunctioning printing heads.

Furthermore, flexibility is vital to accommodate the dynamic movements and requirements of inkjet printing systems, ensuring smooth ink flow and consistent performance.

A smooth outer surface enhances the tube's sliding properties, facilitating seamless ink flow and minimizing friction-related issues during printing operations.

Lastly, ensuring flame retardancy mitigates potential safety hazards, safeguarding both the printer and the printing environment.

In essence, selecting a high-quality tube for inkjet printers is paramount to achieving optimal printing results, ensuring ink stability, and maintaining the integrity of the printing process.

So, in our project we hope to use a solvent resistance ink tube with above qualities for the propagation of ink.

14.Schematics for the selected conceptual design.

### 14.1 Main Block Diagram

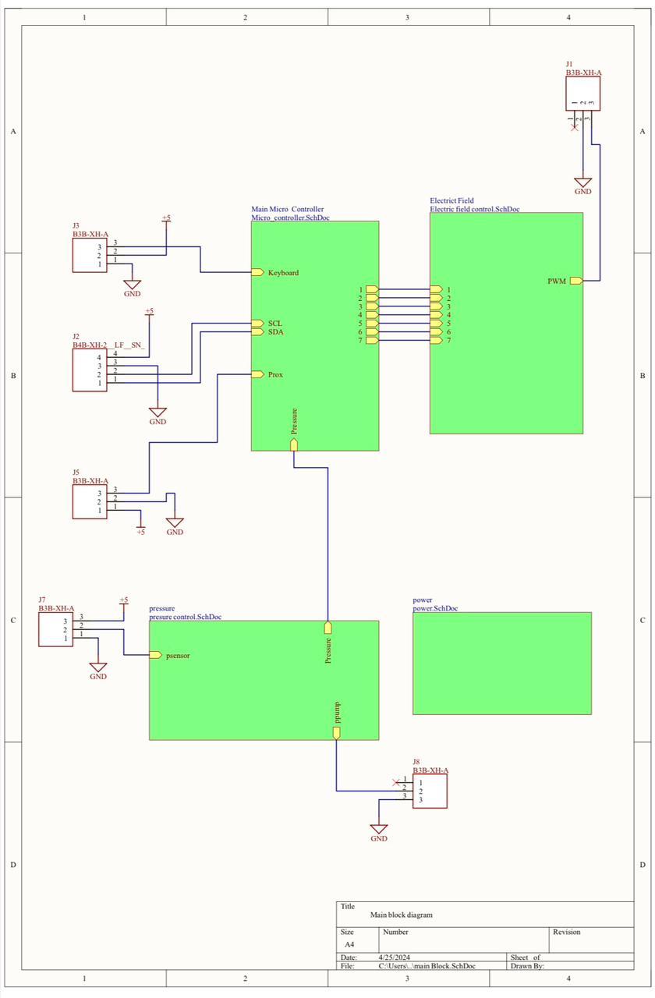
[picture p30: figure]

### 14.2 Main Controller

### 14.3 Electric Field Controller

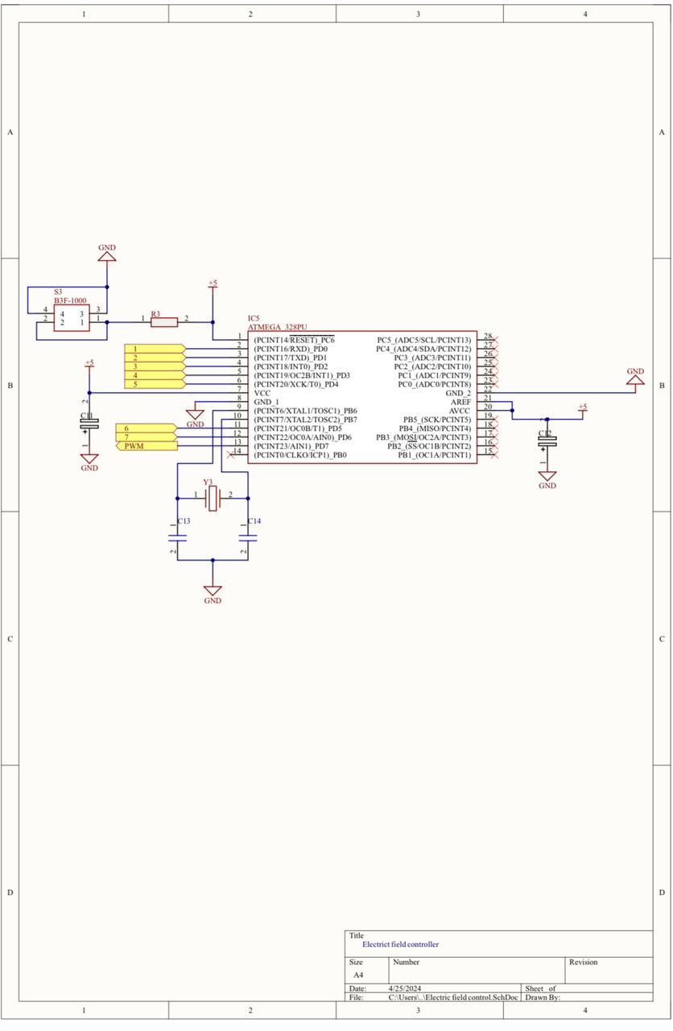
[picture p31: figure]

### 14.4 Pressure Controller

### 14.5 Power Supply

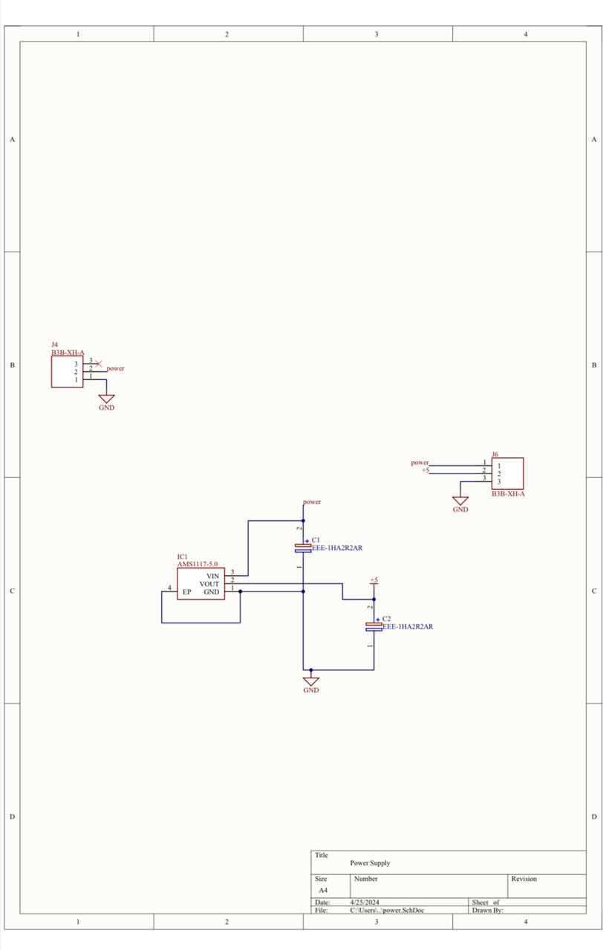
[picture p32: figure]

## 15.PCB Design and 3D view

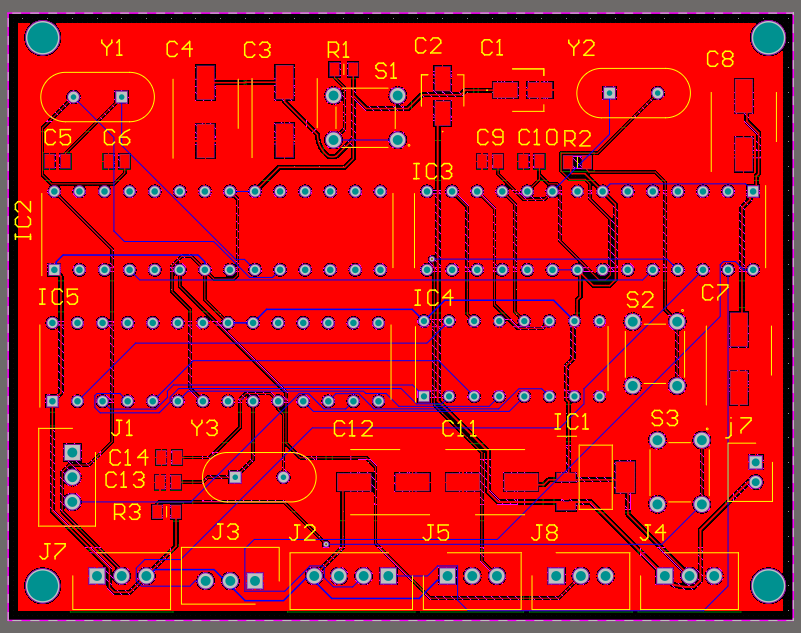
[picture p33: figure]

## 16.Enclosure Designs


1. Print Controller Enclosure Designs.


Design Tree and Assembly

## 17.References

[1]
“Continuous Inkjet Printer,” Hitachi Industrial. https://hitachi-industrial.eu/codingsolutions/products-solutions/continuous-inkjet-printer/

[2]
“Industrial Printers, Coders and Markers,” www.domino-printing.com. https://www.domino-printing.com/en/home.aspx

[3]
“Stakeholder Mapping. The Basics | Smaply Blog,”
www.smaply.com.
https://www.smaply.com/blog/stakeholdermaps

[4]
“Concept design process: Overview,” www.inclusivedesigntoolkit.com. https://www.inclusivedesigntoolkit.com/GS_overview/overview.html

[5]
Wikipedia Contributors, “Inkjet printing,” Wikipedia, Dec. 23, 2019. https://en.wikipedia.org/wiki/Inkjet_printing

[6]

Annac (2023) Types of printer ink: Explained, Printer Guides and Tips from LD Products. Available at:

https://www.ldproducts.com/blog/paper-and-ink-combinations-know-your-ink-part-2/

[7]

Dye-based ink versus pigmented ink. Available at:

https://dtm-print.eu/en/pages/dye-versus-pigment.html

[8]

Pacinio, J. (2023) Battle of inks: Pigment vs dye – which is the best suitor for an inkjet printer, Cartridge World: Printer Cartridges & Services. Available at:

https://cartridgeworldusa.com/blog/battle-of-inks-pigment-vs-dye-which-is-the-best-suitor-for-an-inkjet-printer (https://cartridgeworldusa.com/blog/battle-of-inks-pigment-vs-dye-which-is-the-best-suitor-for-an-inkjet-printer)

[9]

Ink-jet printers (no date) HAKKO CORPORATION as a Pioneer for Processing Resin Hose; High Quality, Made in Japan. Available at:

https://hakko-eightron.com/inkjet/

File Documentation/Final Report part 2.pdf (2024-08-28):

## Department of Electronic and Telecommunication Engineering

## University of Moratuwa


## EN2160 - Electronic Design Realization

## Automatic Batch Code Printer

Design Details Report

Anjula M.K | 210368V

Meemanage N.A 210385U

## Contents

# I. Comprehensive Design Details

A. Introduction to the proposed printing process.

The process of batch code printing involves several intricate steps orchestrated by multiple ATmega chips to ensure efficient and accurate printing on various surfaces. Here's a refined description of the procedure:

The printing process begins with an ATmega chip generating bit patterns (matrices) for alphanumeric characters. Each character input by the user is translated into a column-by-column bit pattern, forming a serial signal for each column. These serial signals, representing the columns of the characters, are transmitted to another ATmega chip through shift registers, where they are converted into voltage signals.

Shift registers play a pivotal role in converting the serial signals into parallel form, facilitating efficient processing and manipulation of the data. They sequentially accept individual bits of the serial data stream and present them simultaneously on multiple output lines in parallel form.

Subsequently, the parallel lines created by the shift registers receive high PWM signals at points corresponding to the highest bits in each column, while lower PWM signals are supplied to other points in the column. Conditional statements are employed to prevent overlapping during printing. If overlap is detected with the previous column, printing is halted; otherwise, PWM signals are supplied to print the column.

Additionally, the first ATmega chip incorporates special functions, such as controlling a proximity sensor to detect the presence of a printing surface near the print head. Another ATmega chip is responsible for regulating the pressure in the ink tank. It adjusts PWM signals based on pressure levels, ensuring optimal printing conditions. Moreover, an analog voltage signal is sent to the first ATmega chip to monitor pressure levels in the tank. If the pressure falls outside the acceptable range, the printing process is aborted until the pressure is corrected.

In summary, the printing process involves meticulous coordination between multiple ATmega chips to generate precise bit patterns, convert serial signals into voltage signals, adjust PWM signals for printing, and monitor printing conditions to ensure high-quality output on various surfaces.

## Advantages

The piezoelectric method of batch code printing, as described, offers several advantages over thermal inkjet and other types of batch code printing, such as using pressure valves. Here are some of the key advantages:

Precision and Quality

- Higher Resolution: The piezoelectric method can produce finer droplets and more precise control over droplet size and placement, leading to higher resolution prints.
- Accurate Bit Patterns: The use of ATmega chips and shift registers ensures that the generated bit patterns for alphanumeric characters are precise, reducing errors and enhancing the clarity of printed codes.

Efficiency and Speed

- Fast Processing: The parallel processing capabilities of shift registers allow for efficient handling of serial data streams, speeding up the printing process.
- Non-Overlapping Printing: Conditional statements to prevent overlapping ensure that printing is smooth and uninterrupted, which enhances overall printing speed and efficiency.

Versatility

- Multiple Surfaces: The proximity sensor integration allows the printer to detect various printing surfaces, making it adaptable to different materials and shapes.
- Variable Print Conditions: The system can adjust PWM signals based on real-time conditions such as pressure levels in the ink tank, ensuring optimal printing on a wide range of surfaces and environments.

Durability and Maintenance

- Less Heat Generation: Unlike thermal inkjet printers, which rely on heat to create ink droplets, the piezoelectric method generates less heat, reducing wear and tear on components and potentially extending the printer's lifespan.
- Reduced Clogging: The absence of heat in the droplet formation process minimizes the risk of ink clogging the nozzles, leading to lower maintenance requirements.

Control and Customization

- Precise Control of Droplet Formation: The ability to control droplet size and frequency through high PWM signals allows for more customized printing outputs.
- Dynamic Adjustment: Real-time monitoring and adjustment of printing parameters (such as pressure in the ink tank) ensure consistent print quality and reduce the likelihood of errors.

Environmental Considerations

- Lower Energy Consumption: Since the piezoelectric method does not rely on heating elements, it generally consumes less energy compared to thermal inkjet printers.
- Less Waste: The precise control over ink droplet formation leads to less ink wastage, making the process more environmentally friendly.

Reliability

- Robust Mechanisms: The integration of multiple ATmega chips to handle various tasks (such as bit pattern generation, proximity sensing, and pressure regulation) ensures a robust and reliable printing process.
- Fail-Safe Operations: Conditional checks and real-time monitoring (e.g., pressure levels) provide fail-safe mechanisms to prevent printing errors and ensure high-quality output.

## B. Detailed Functionality of the circuit

This module is an integral component designed for taking user input via a keyboard and a display, subsequently converting the input into a printable format for batch code printing. It is specifically developed to ensure precise and reliable printing of batch codes, which are crucial for product identification and tracking in various industries. The detailed functionalities, including text input processing, bitmap mapping, signal generation, and additional control features, are outlined below:

1. User Input and Display Interface: The circuit is designed to take user input through a keyboard and display the input on a screen. This allows the user to enter the desired text for batch codes and verify it before printing.
2. ASCII to Bitmap Conversion: Once the text is entered, a program maps the ASCII characters of the text into a bitmap format suitable for dot matrix printing. This conversion ensures that each character is accurately represented as a series of dots.
3. Column Activation Signal Generation: The module determines which positions of the dot matrix columns should be activated based on the bitmap representation. This information is then converted into a serial signal.
4. Shift Register Communication: The serial signal containing the column activation information is sent to a shift register. The shift register processes this serial signal and outputs it to another microcontroller.
5. Microcontroller and PWM Signal Creation: The secondary microcontroller receives the column activation information from the shift register. It then checks which positions are activated and generates a corresponding PWM (Pulse Width Modulation) signal as the output.
6. Proximity Sensor Integration: The module includes a proximity sensor to detect whether an item is nearby. This ensures that the printing process is initiated only when the item is in the correct position, preventing misprints and ensuring accuracy.
7. Ink Pressure Monitoring and Control: Another microcontroller is dedicated to checking the ink pressure and controlling the ink flow. This ensures consistent and high-quality printing by maintaining optimal ink pressure throughout the printing process.

By integrating user input processing, precise bitmap mapping, reliable signal generation, proximity detection, and ink flow control, this module provides a comprehensive solution for batch code printing. These features are essential for product tracking and quality control in various applications, ensuring precision and reliability in the printing process.

1. Main microcontroller.


The main microcontroller serves as the central component of our system it is programmed by Microchip studio platform. It performe crucial tasks to ensure seamless operation. It processes user input from a keyboard and display, allowing users to input and verify text for batch code printing. This text is then converted into a bitmap format, translating each character into a dot matrix representation essential for accurate printing. The microcontroller generates a serial signal from this bitmap data to indicate which dot matrix columns should be activated, sending this signal to a shift register for further processing.

In addition to managing text input and conversion, the main microcontroller integrates with a proximity sensor to detect the presence of an item, ensuring that printing occurs only when the item is correctly positioned. This prevents misprints and enhances accuracy. It also communicates with a secondary microcontroller responsible for monitoring ink pressure and controlling ink flow, maintaining consistent and high-quality printing by adjusting the ink pressure as needed.

By LATCH, CLOCK and DATA pin it sends data to shift register to decode from there. SCL and SDA pins are used to initiate the OLED Display. Keyboard is connected to analog pin 3 and it initiate proper action based on the analog voltage value is received. Proximity sensor is connected to Analog pin 2. The pressure measurement value from the pressure controller is received by Analog pin 1.

By coordinating these tasks and managing communication between various system components, the main microcontroller ensures the overall efficiency and reliability of the batch code printing system, essential for accurate product identification and tracking.

Component list of power supply circuit

item | quantity | reference | part
1 | 1 | IC3 | 8-bit AVR Microcontroller with 32K Bytes In-System Programmable Flash
2 | 1 | S2 | Tactile Switches 6X6 Flat 4.3mm Btn Force 100g w/o Grd
3 | 1 | Y2 | Crystals CRYSTAL 16.1280MHZ 18PF T/H
4 | 1 | R2 | Thick Film Resistors -SMD 100 OHM 1% 1/2W
5 | 2 | C7,C8 | Aluminum Electrolytic Capacitors - SMD 25V 10uF 20%
6 | 2 | C9 , C10 | Multilayer Ceramic Capacitors MLCC -SMD/SMT 25V 2.2uF X7R 0805 1 0% AEC-Q200 FLEXITER

2. Power supply circuit.


This power supply module is designed to provide a stable 2A maximum current output using the AMS1117 regulator IC, ensuring consistent performance and reliability for various ICs and components on a PCB. The AMS1117 regulator offers high-precision fixed voltage regulation and can handle up to 2A of current, making it suitable for a wide range of applications, from small electronic devices to larger systems. It accepts a broad input voltage range, typically from 4.5V to 15V, allowing compatibility with various power sources such as batteries, wall adapters, and other external supplies. The regulator includes built-in thermal protection to prevent overheating and short-circuit protection to safeguard against accidental shorts, enhancing the system's overall reliability. With a low dropout voltage of approximately 1.1V at 2A, the AMS1117 ensures efficiency even when the input voltage is close to the output voltage. The compact design of the power supply module allows for easy integration into space-constrained applications. Additionally, the inclusion of input and output capacitors for filtering helps smooth out voltage fluctuations and reduce noise, providing a clean and stable power supply for sensitive electronic components. This comprehensive design makes the power supply module an efficient and reliable solution for powering various ICs and components in electronic applications.

By pass capasitors have been added to input and output pins to filterout any high frequency noices that can effect the smooth operation of ICs.

Component list of power supply circuit

item | quantity | reference | part
1 | 1 | IC1 | 1A LOW DROPOUT VOLTAGE REGULATOR
2 | 2 | C1 , C2 | Aluminum Electrolytic Capacitors - SMD 2.2UF 50V VS SMD
3 | 2 | J4 , J6 | Connector Header Through Hole 3 position 0.098" (2.50mm)
3. Proximity Sensor.

The proximity sensor that have been used is FA-CDD-40N .The CDD-40N photoelectric sensor is a diffuse reflection sensor designed for precise object detection within a range of up to 40 cm. It operates by emitting an infrared light beam that reflects off an object's surface and detecting the reflected light. The sensor features an NPN open drain output, capable of sinking current up to 100mA with a maximum input voltage of 30VDC, making it

suitable for interfacing with various control systems. It operates on a power supply range of 10-30 VDC, with a 10% ripple tolerance for stable performance. The sensor includes a 2-meter cable for flexible installation and has compact dimensions of 69 mm in length and 18 mm in diameter. It functions effectively within a temperature range of -25 to 55 degrees Celsius and boasts a fast response time of 1.5 milliseconds. Utilizing an infrared light source, it provides reliable performance in diverse lighting conditions with minimal interference. With a maximum lag phase of 10%, the CDD-40N ensures quick detection and signal output, making it ideal for applications in industrial automation, packaging, safety systems, robotics, and material handling.

4. Keyboard


The keyboard that have been used is MD0414 it inputs 5 v and current of 100mA. It out puts Analog voltage based on the key that have been pressed. It have 5 keys , 4 arrow keys for direction and an enter key. We can display the characters on the key board and user can use the key board to choose the combination of the cracters to input for printing.

5. Shift Registers


The shift register is a crucial component in the batch code printing system, responsible for converting serial signals into parallel signals to precisely control the printing mechanism. Its primary functionalities include serial-to-parallel conversion, data storage, shifting, and parallel output.

Firstly, the shift register receives serial data from the main microcontroller latch and clock pins syncronise the data stream and data pin receives the serial data specifying which columns of the dot matrix should be activated for printing. This serial data is then stored in the shift register's internal registers. As new bits of serial data are received, the existing bits are sequentially shifted to ensure proper alignment and sequencing.

Once all serial data has been received and stored, the shift register converts it into parallel signals. Each bit in the parallel output corresponds to the state (activated or deactivated) of a specific column in the dot matrix. This parallel output is crucial for enabling precise control over the printing process, ensuring accurate placement of dots to form batch codes.

6. Secondary Microcontroller


The secondary microcontroller enhances the batch code printing process by generating Pulse Width Modulation (PWM) signals based on the activated dot matrix columns. Its primary functionality lies in PWM signal generation and coordination with the main microcontroller.It takes sense inputs from digital pins 0 to 6 and output the PWM in Digital pin 7.

Upon receiving parallel signals from the shift register, the secondary microcontroller interprets which dot matrix columns are activated. It then creates PWM signals based on this information, determining the timing and intensity of dot placements on the item being printed.

Component list of power supply circuit

item | quantity | reference | part
1 | 1 | IC5 | 8-bit AVR Microcontroller with 32K Bytes In-System Programmable Flash
2 | 1 | S3 | Tactile Switches 6X6 Flat 4.3mm Btn Force 100g w/o Grd
3 | 1 | Y3 | Crystals CRYSTAL 16.1280MHZ 18PF T/H
4 | 1 | R3 | Thick Film Resistors -SMD 100 OHM 1% 1/2W
5 | 2 | C11,C12 | Aluminum Electrolytic Capacitors - SMD 25V 10uF 20%
6 | 2 | C13 , C14 | Multilayer Ceramic Capacitors MLCC -SMD/SMT 25V 2.2uF X7R 0805 1 0% AEC-Q200 FLEXITER

7. Pressure controlling system.


The pressure monitoring microcontroller is a critical component in our batch code printing system, dedicated to maintaining optimal ink pressure for consistent and high-quality printing. It reads pressure values from a sensor within the ink supply system and continuously monitors them to ensure they remain within the optimal range. Based on these readings, the microcontroller generates Pulse Width Modulation (PWM) signals to control the speed and flow of ink to the printing mechanism. This precise control prevents issues such as over-inking or under-inking, ensuring consistent print quality. The pressure monitoring microcontroller communicates with the main microcontroller, providing real-time pressure data. The main microcontroller evaluates these readings against predefined thresholds and can halt the printing process if the pressure exceeds or falls below the optimal range, thereby preventing printing defects. By maintaining stable ink pressure, the pressure monitoring microcontroller enhances the reliability and efficiency of the batch code printing system, crucial for accurate product identification and traceability in industrial applications. It takes Input from the sensor to Digital pin 2 and gives the PWM to pressure control curicuit through Digital pin 4 and it gives scaler voltage of the pressure to main controller through Analog pin 5

Components of Pressure control circuit

item | quantity | reference | part
1 | 1 | IC2 | 8-bit AVR Microcontroller with 32K Bytes In-System Programmable Flash
2 | 1 | S1 | Tactile Switches 6X6 Flat 4.3mm Btn Force 100g w/o Grd
3 | 1 | Y1 | Crystals CRYSTAL 16.1280MHZ 18PF T/H
4 | 1 | R1 | Thick Film Resistors -SMD 100 OHM 1% 1/2W
5 | 2 | C3,C4 | Aluminum Electrolytic Capacitors - SMD 25V 10uF 20%
6 | 2 | C5 , C6 | Multilayer Ceramic Capacitors MLCC -SMD/SMT 25V 2.2uF X7R 0805 1 0% AEC-Q200 FLEXITER

8. Pressure sensor.


The WNK811 pressure sensor that have been used is designed to measure pressures within a range of -1 to 60 MPa with high accuracy, ensuring precise monitoring and control in various applications. Manufactured by WNK and certified with CE, it offers an accuracy of 1% FS and supports multiple output signals including 4-20mA, 0.5-4.5V, i2c, and others, providing flexibility for integration into different systems. The sensor operates effectively within a wide temperature range of -40 to 85°C and can measure pressures up to 10 bar. It is powered by various DC voltages (24VDC, 12VDC, 5VDC, 8-30VDC), enhancing its versatility. Constructed from durable materials such as 304 stainless steel and 316L, it is suitable for use with a range of media including water, liquids, gases, steam, oil, and lubricants. The sensor features various pressure port options (G1/4, G1/2, 1/8NPT, 1/4NPT, and others) to accommodate different connection requirements. Additionally, it can withstand overload pressures up to twice its full scale (FS) and proof pressures up to three times FS, ensuring robust performance in demanding environments.

9. Display


The OLED display operates efficiently across a voltage range of 3.3V to 5V .It offer a vibrant visual experience with its 128 × 64 pixel resolution and 0.15 × 0.15 mm pixel size. It is supported by the SSD1315 driver to integrates seamlessly via 4-wire SPI or I2C interfaces ensuring compatibility with various microcontrollers. The 26.00 × 26.00 mm module size provides a compact yet detailed viewing area. It is available in configurations such as upper yellow & lower blue (C), white (D) and blue (E and it caters to diverse aesthetic preferences and application needs making it suitable for compact electronics requiring high-resolution
graphical displays.

## II. PCB Design and 3D view


Figure 1


Figure 2

Figure 3

## III. Photograph of the bare PCB


Bare PCB figure 1

Bare PCB figure 2

## IV. Photograph of the soldered PCB


Soldered PCB figure 1


Soldered PCB figure 2

## V. Photographs as evidence for PCB testing


PCB testing figure 1

PCB testing figure 2

## VI. Enclosure Design of the print Controller


## A. Design Tree


## B. Enclosure Lid

## C. Upper Cover of the ink tank inside the main enclosure

## D. Enclosure Assembly


# VII. Detailed Design Drawings


# VIII. Photographs of the physically built enclosure


Figure 1


Figure 2


Figure 3

Figure 4

# IX. Detailed Programming Information


## X. Daily Log Entries

Project Title: Automatic Batch Code Printing Machine Development

01/02/2024 - Project Selection (Part 1)

- Organized a project kickoff meeting.
- Conducted market research to identify potential improvements within the industry, generating several project ideas and proposals.

04/02/2024 - Project Selection (Part 2)

- Selected the best project idea to support local industries, focusing on an automatic batch code printing machine.
- Conducted preliminary research on current batch code printing machines, noting key features and functionalities.

10/02/2024 - Project Evaluation

- Conducted a self-evaluation of the selected project.

16/02/2024 - Self Review

- Conducted market research to identify stakeholders, users, and competitors.

28/02/2024 - Generating Preliminary Designs

- Developed various stimulated ideas for different printing techniques to achieve the required output.
- Created three different conceptual designs based on these ideas.

04/03/2024 - Evaluation of Conceptual Designs

- Selected the best conceptual design for further progress based on evaluation criteria.

12/03/2024 - Designing of the Circuit (Part 1)

- Began designing the circuit layout, focusing on organizing key components such as input devices (keyboard, display), power supply, pressure sensors, and proximity sensors.
- Sketched initial circuit layouts on paper, outlining potential pathways for power and signal flow.
- Explored different methods of obtaining the control signal required to generate the electric field.

20/03/2024 - Designing of the Circuit (Part 2)

- Selected the best circuit components suited to the initial functions of the batch code printer.

21/03/2024 - Designing of the Circuit (Part 3)

- Created preliminary schematics of the circuit layout to ensure proper connections between all components.
- Further refined the circuit design, integrating the microcontroller and communication interfaces.

25/03/2024 - Program Implementation (Part 1)

- Designed an algorithm to map ASCII characters of given text to their respective bitmap representation in a dot matrix.
- Developed an algorithm to shift the bitmap representation of each character column by column to achieve the scrolling effect.
- Developed C++ code for the designed algorithm.

28/03/2024 - Program Implementation (Part 2)

- Designed an algorithm to establish the connection between sensors and handle user inputs, and developed the corresponding C++ code.
- Finalized the implemented code.

07/04/2024 - Schematic Design (Part 1)

- Began developing digital schematics, concentrating on logical arrangement for clarity and ease of understanding.

11/04/2024 - Schematic Design (Part 2)

- Continued developing and refining the schematic design to ensure all essential components and connections are accurately depicted.
- Held a design review with the team to ensure schematic consistency and completeness.
- Incorporated necessary adjustments based on feedback from the supervisor.

17/04/2024 - PCB Layout (Part 1)

- Transitioned from schematic design to PCB layout, beginning with component placement on the board.
- Emphasized optimal positioning to maintain signal integrity and manage power effectively.
- Considered size limitations and arrangement of crucial interfaces.

19/04/2024 - PCB Layout (Part 2)

- Continued routing connections between components, ensuring all signal paths are optimized for minimal interference and maximum signal integrity.
- Used design rules and guidelines to meet industry standards and manufacturing requirements.
- Implemented design techniques such as impedance matching for high-speed signal paths to minimize reflections and signal degradation.
- Addressed potential noise sources, such as switching regulators or high-speed digital signals, and implemented strategies to mitigate their effects on sensitive analog and digital circuits.
- Verified that all trace widths and clearances were within specifications to handle both power and signal lines effectively.

21/04/2024 - PCB Layout (Part 3)

- Double-checked the layout for any potential design rule violations and corrected them as needed.

- Ensured all components are correctly placed and oriented according to the design specifications.
- Conducted an exhaustive design review, meticulously verifying the PCB layout against the schematic and project requirements.
- Implemented optimizations to enhance manufacturability and facilitate ease of assembly.

23/04/2024 - Enclosure Design (Part 1)

- Discussed the enclosure requirements, covering aspects like dimensions, material selection, and functionality requirements for the print head.
- Developed initial design sketches for the enclosure, considering optimal placement options for the pressure tank, display, pressure valves, and PCB designs.
- Explored various enclosure materials, evaluating factors such as cost-effectiveness, durability, and suitability for environmental conditions.

25/04/2024 - Enclosure Design (Part 2)

- Implemented design modifications to incorporate connectors, vents, and mounting features.
- Integrated cable management solutions to ensure tidy organization within the enclosure.

28/04/2024 - Enclosure Design (Part 3)

- Conducted a design review meeting to evaluate the enclosure's compatibility with the PCB and overall system.
- Finalized the enclosure design.

29/04/2024 - PCB Production & Component Ordering

- Submitted the finalized PCB design files to a manufacturer for production, ensuring adherence to manufacturing guidelines and specifications.
- Ordered necessary components, including resistors, capacitors, ICs, connectors, and other required sensors.
- Reviewed and updated the Bill of Materials (BOM) to reflect any changes or substitutions made during the component ordering process.

07/05/2024 - Component Arrival & Preparation

- Received the manufactured PCBs and all ordered components.
- Conducted a thorough inspection of the PCBs to ensure they meet quality standards and comply with design specifications.
- Organized and categorized the components to facilitate smooth and efficient assembly processes.

10/05/2024 - PCB Assembly & Soldering (Part 1)

- Started assembling components onto the PCB following design specifications.
- Carefully placed and soldered each component, starting with smaller ones and progressing to larger ones.
- Conducted intermediate visual inspections to check for any soldering defects or misalignments.
- Checked solder joints for continuity to ensure proper electrical connections.
- Completed assembly and soldering of the PCB.
- Cleaned assembled PCBs to remove any remaining flux residue and inspected them for any remaining issues.

12/05/2024 - Project Final Documentation

- Created comprehensive documentation covering the entire project from inception to completion.

## XI. References

[1] alldatasheet.com, “AMS1117-5.0 PDF,” pdf1.alldatasheet.com.

https://pdf1.alldatasheet.com/datasheet-pdf/view/205692/ADMOS/AMS1117-5.0.html (accessed Jul. 05, 2024).

[2]
“XH CONNECTOR.” Available: https://www.jst-mfg.com/product/pdf/eng/eXH.pdf

[3]“ATmega328P 8-bit AVR Microcontroller with 32K Bytes In-System Programmable Flash DATASHEET.” Available:

https://ww1.microchip.com/downloads/aemDocuments/documents/MCU08/ProductDocuments/DataSheets/Atmel-7810-Automotive-Microcontrollers-ATmega328P_Datasheet.pdf (https://ww1.microchip.com/downloads/aemDocuments/documents/MCU08/ProductDocuments/DataSheets/Atmel-7810-Automotive-Microcontrollers-ATmega328P_Datasheet.pdf)

[4]“B3F Tactile Switch Through-hole-mounting Switches in a Wide Range of Models: 6 × 6 mm, 12 × 12 mm, Side-operated Models, Gold-plated Contacts, and Radial Tape.” Available: https://www.mouser.com/datasheet/2/307/en-b3f-13826.pdf

[5]“Hidden Creek Ln Spicewood TX 78669 5101.” Accessed: Jul. 05, 2024. [Online]. Available: https://www.mouser.com/datasheet/2/3/ABL-1774766.pdf

[6]“General Specifications GENERAL DESCRIPTION Automotive MLCC with FLEXITERM ®.” Accessed: Jul. 05, 2024. [Online]. Available: https://www.mouser.com/datasheet/2/40/AutoMLCCKAF-3218225.pdf

## XII. Appendix: Initial Code by Arduino

#include <SPI.h>

#include <Wire.h>

#include <Adafruit_GFX.h>

#include <Adafruit_SSD1306.h>

#define SCREEN_WIDTH 128

#define SCREEN_HEIGHT 64

int Keyboard=A7;

int New_X=0;
int Old_X=0;
int New_Y=0;
int Old_Y=0;

int Key_read=0;
int Prev_Key_read=1023;
boolean Key_pressed=false;

// String variable holding the text to transmit char To_Transmit="";

// Length of the text to transmit
int To_Transmit_Length=0;

#define OLED_RESET 4

Adafruit_SSD1306 display(SCREEN_WIDTH, SCREEN_HEIGHT, &Wire, OLED_RESET);

// Used for displaying Leter board
char Letters[3][9]={"ABCDEFGHI", "JKLMNOPQR",
"STUVWXYZ_"};

char msg[] ="";
int scrollspeed = 35;

int x;
int y;

// Rows (Vertical control)
int clockPin2 = 2; // pin connected to Clock Pin 11 of 74HC595 int latchPin2 = 7; // pin connected to Latch Pin 12 of 74HC595 int dataPin2 = 3;
int psensor= 24;
int proxy = 25;

// FONT DEFINITION
byte alphabets[][5] = {
{0,0,0,0,0}, | // space | ASCII 32
{0,0,253,0,0}, | // ! | ASCII 33
{0,96,0,96,0}, | // " | ASCII 34
{20,127,20,127,20}, | // # | ASCII 35
{36,42,127,42,18}, | // $ | ASCII 36
{17,2,4,8,17}, | // % | ASCII 37
{54,73,85,34,5}, | // & | ASCII 38
{0,0,104,112,0}, | // ' | ASCII 39
{28,34,65}, | // ( | ASCII 40
{65,34,28}, | // ) | ASCII 41
{20,8,62,8,20}, | // * | ASCII 42
{8,8,62,8,8}, | // + | ASCII 43
{0,0,5,6,0}, | // , | ASCII 44
{8,8,8,8,8}, | // - | ASCII 45
{0,0,1,0,0}, | // . | ASCII 46
{1,2,4,8,16}, | // / | ASCII 47
{62,69,73,81,62}, | // 0 | ASCII 48
{0,33,127,1,0}, | // 1 | ASCII 49
{33,67,69,73,49}, | // 2 | ASCII 50
{66,65,81,105,70}, | // 3 | ASCII 51
{12,20,36,127,4}, | // 4 | ASCII 52
{113,81,81,81,78}, | // 5 | ASCII 53
{30,41,73,73,6}, | // 6 | ASCII 54
{64,64,79,80,96}, | // 7 | ASCII 55
{54,73,73,73,54}, | // 8 | ASCII 56
{48,73,73,74,60}, | // 9 | ASCII 57
{0,0,54,54,0}, | // : | ASCII 58
{0,0,53,54,0}, | // ; | ASCII 59
{0,8,20,34,65}, | // < | ASCII 60
{20,20,20,20,20}, | // = | ASCII 61

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
, | // > | ASCII 62
{32

,64

,69

,72

,48

}

, | // ? | ASCII 63
{38

,73

,77

,65

,62

}

, | // @ | ASCII 64
{31

,36

,68

,36

,31

}

, | // A | ASCII 65
{127

,73

,73

,73

,54

}

, | // B | ASCII 66
{62

,65

,65

,65

,34

}

, | // C | ASCII 67
{127

,65

,65

,34

,28

}

, | // D | ASCII 68
{127

,73

,73

,65

,65

}

, | // E | ASCII 69
{127

,72

,72

,72

,64

}

, | // F | ASCII 70
{62

,65

,65

,69

,38

}

, | // G | ASCII 71
{127

,

8

,

8

,

8

,127

}

, | // H | ASCII 72
{

0

,65

,127

,65

,

0

}

, | // I | ASCII 73
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
,126

}

, | // J | ASCII 74
{127

,

8

,20

,34

,65

}

, | // K | ASCII 75
{127

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
, | // L | ASCII 76
{127

,32

,16

,32

,127

}

, | // M | ASCII 77
{127

,32

,16

,

8

,127

}

, | // N | ASCII 78
{62

,65

,65

,65

,62

}

, | // O | ASCII 79
{127

,72

,72

,72

,48

}

, | // P | ASCII 80
{62

,65

,69

,66

,61

}

, | // Q | ASCII 81
{127

,72

,76

,74

,49

}

, | // R | ASCII 82
{50

,73

,73

,73

,38

}

, | // S | ASCII 83
{64

,64

,127

,64

,64

}

, | // T | ASCII 84
{126

,

1

,

1

,

1

,126

}

, | // U | ASCII 85
{124

,

2

,

1

,

2

,124

}

, | // V | ASCII 86
{126

,

1

,

6

,

1

,126

}

, | // W | ASCII 87
{99

,20

,

8

,20

,99

}

, | // X | ASCII 88
{96

,16

,15

,16

,96

}

, | // Y | ASCII 89
{67

,69

,73

,81

,97

}

, | // Z | ASCII 90
{

0

,127

,65

,65

,

0

}

, | // [ | ASCII 91
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
, | //
| \ | ASCII 92
{

0

,65

,65

,127

,

0

}

, | // ] | ASCII 93
{16

,32

,64

,32

,16

}

, | // ^ | ASCII 94
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
, | // _ | ASCII 95
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
, | // ` | ASCII 96
{

2

,21

,21

,21

,15

}

, | // a | ASCII 97
{127

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
, | // b | ASCII 98
{14

,17

,17

,17

,

2

}

, | // c | ASCII 99
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
,127

}

, | // d | ASCII 100
{14

,21

,21

,21

,12

}

, | // e | ASCII 101
{

8

,63

,72

,64

,32

}

, | // f | ASCII 102
{24

,37

,37

,37

,62

}

, | // g | ASCII 103
{127

,

8

,16

,16

,15

}

, | // h | ASCII 104
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
, | // i | ASCII 105
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
, | // j | ASCII 106

{127,4,10,17,0}, | // k | ASCII 107
{0,65,127,1,0}, | // l | ASCII 108
{31,16,12,16,31}, | // m | ASCII 109
{31,8,16,16,15}, | // n | ASCII 110
{14,17,17,17,14}, | // o | ASCII 111
{31,20,20,20,8}, | // p | ASCII 112
{8,20,20,12,31}, | // q | ASCII 113
{31,8,16,16,8}, | // r | ASCII 114
{2,21,21,21,9}, | // s | ASCII 115
{16,126,17,1,2}, | // t | ASCII 116
{30,1,1,2,31}, | // u | ASCII 117
{28,2,1,2,28}, | // v | ASCII 118
{30,1,6,1,30}, | // w | ASCII 119
{17,10,4,10,17}, | // x | ASCII 120
{24,5,5,5,30}, | // y | ASCII 121
{17,19,21,25,17}, | // z | ASCII 122
{0,0,8,54,65}, | // { | ASCII 123
{0,0,127,0,0}, | // | | ASCII 124
{65,54,8,0,0}, | // } | ASCII 125/Z
};

void setup() {
pinMode(latchPin2, OUTPUT); pinMode(clockPin2, OUTPUT); pinMode(dataPin2, OUTPUT); pinMode(psensor, INPUT);
pinMode(proxy, INPUT);
setupDispaly();

}
void setupDispaly() {
Serial.begin(9600);

// SSD1306_SWITCHCAPVCC = generate display voltage from 3.3V internally if(!display.begin(SSD1306_SWITCHCAPVCC, 0x3C)) { // Address 0x3D for 128x64 Serial.println(F("SSD1306 allocation failed"));
for(;;); // Don't proceed, loop forever
}
display.display();
delay(2000); // Pause for 2 seconds

display.clearDisplay();

display.display();

display.fillRect(0, 0, 128, 15, SSD1306_INVERSE); display.drawRect(110, 2, 16, 12, SSD1306_BLACK); display.setTextSize(1);
display.setTextColor(SSD1306_BLACK); display.setCursor(113,4);
display.println("OK");
display.display();
// Display Letter Board 3 rows 9 character in each row display.setTextSize(2);
display.setTextColor(SSD1306_WHITE);
for (int j=0; j<3;j++){
for (int i=0; i<9;i++){
display.setCursor(i*12+2*i+1,j*16+17); display.println(Letters[j][i]); delay(10);
display.display();
}
}

display.fillRect(0, 16, 12, 16, SSD1306_INVERSE); display.display();

}

void Highlight_letter(int X, int X_Old, int Y, int Y_Old){

display.fillRect(X*12+2*X, Y*16 +16, 12, 16, SSD1306_INVERSE);

display.fillRect(X_Old*12+2*X_Old, Y_Old*16 +16, 12, 16, SSD1306_INVERSE);

display.display();
}
void Selecttext() {
Key_read =analogRead(Keyboard);
if (Prev_Key_read>1000 and Key_read<1000){
Key_pressed=true;
if (Key_read<10 and Old_X>0) New_X=Old_X-1;
if (Key_read>160 and Key_read<170 and Old_X<9) New_X=Old_X+1;

if (Key_read>25 and Key_read<35 and Old_Y>-1) New_Y=Old_Y-1; if (Key_read>80 and Key_read<90 and Old_Y<2 ) New_Y=Old_Y+1; if (Key_read>350 and Key_read<360) {
if (New_Y!=-1){
To_Transmit=To_Transmit + Letters[New_Y][New_X]; To_Transmit_Length++;
display.setTextSize(1);
display.setCursor(3,1);
display.setTextColor(BLACK ); display.fillRect(0, 0, 100, 15, SSD1306_WHITE); display.println(To_Transmit); display.display();
}
else{
for (int i=1;i<9;i++) {
display.fillRect(0, 0, 128, 15, SSD1306_INVERSE); delay(300);
display.display();
}
}
}

if (New_Y==-1 and Old_Y==0){
display.fillRect(110, 2, 16, 12, SSD1306_INVERSE); display.fillRect(Old_X*12+2*Old_X, Old_Y*16 +16, 12, 16, SSD1306_INVERSE);
}
if (New_Y==0 and Old_Y==-1){
display.fillRect(110, 2, 16, 12, SSD1306_INVERSE); display.fillRect(New_X*12+2*New_X, New_Y*16 +16, 12, 16, SSD1306_INVERSE);
Prev_Key_read=Key_read;
Old_X=New_X;
Old_Y=New_Y;;
}
if ((Old_X!=New_X or Old_Y!=New_Y) and Old_Y!=-1 ){
if (New_Y!=-1 )Highlight_letter (New_X,Old_X,New_Y,Old_Y); Old_X=New_X;
Old_Y=New_Y;
}
}

display.display();
Prev_Key_read=Key_read;

}

void RefreshDisplay()
{
for (int row = 0; row < 8; row++) {
int rowData = 1 << row;
int rowBits = bitmap[row];

digitalWrite(latchPin2, LOW); shiftOut(dataPin2, clockPin2, MSBFIRST, rowBits); shiftOut(dataPin2, clockPin2, MSBFIRST, rowData); digitalWrite(latchPin2, HIGH);
}
}

void Plot(int x, int y, bool isOn) {
int row = y;
int colBit = 1 << (7 - x);
if (isOn)
bitmap[row] |= colBit;
else
bitmap[row] &= ~colBit;
}

void XProcess()
{
for (int charIndex = 0; charIndex < (sizeof(msg) - 1); charIndex++) {
int alphabetIndex = msg[charIndex] - ' ';
if (alphabetIndex < 0) alphabetIndex = 0;

for (int row = 0; row < 8; row++)
{
bool isOn = bitRead(alphabets[alphabetIndex][row], 0) == 1;
Plot(0, row, isOn); ly
}
for (int refreshCount = 0; refreshCount < scrollspeed; refreshCount++) RefreshDisplay();
}

}

void loop() {

Selecttext();
msg[]=To_Transmit;
if(digitalRead(psensor) == HIGH && digitalRead(proxy) == HIGH){ XProcess();

}

}

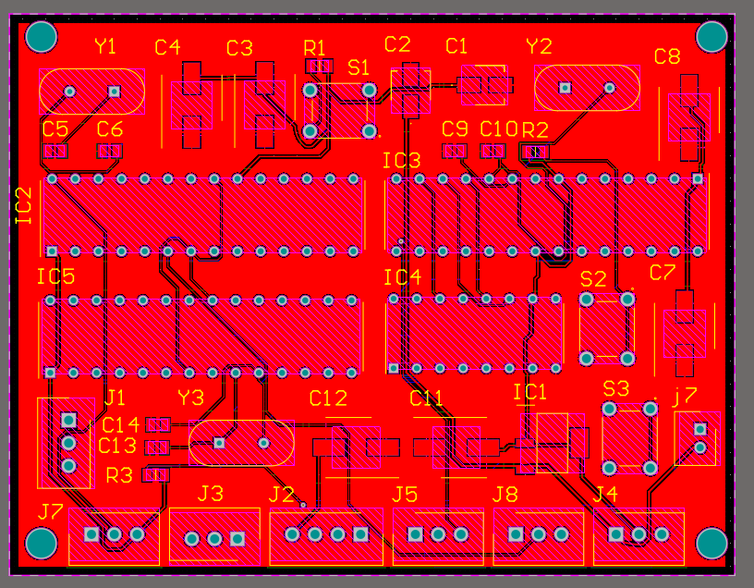
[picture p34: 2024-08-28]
Images/2nd Layer PCB.png

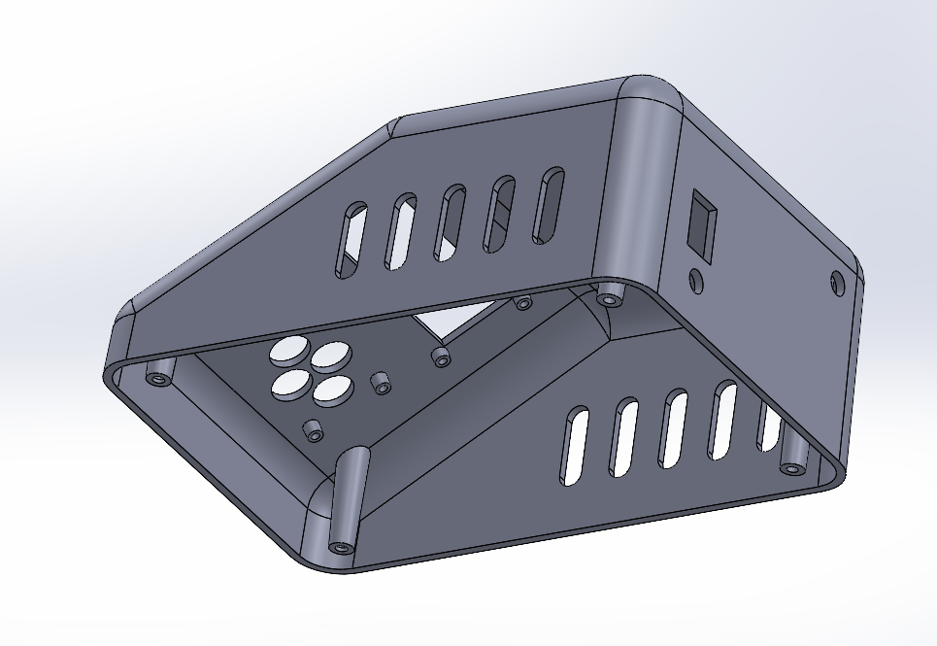
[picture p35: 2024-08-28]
Images/top 2.png

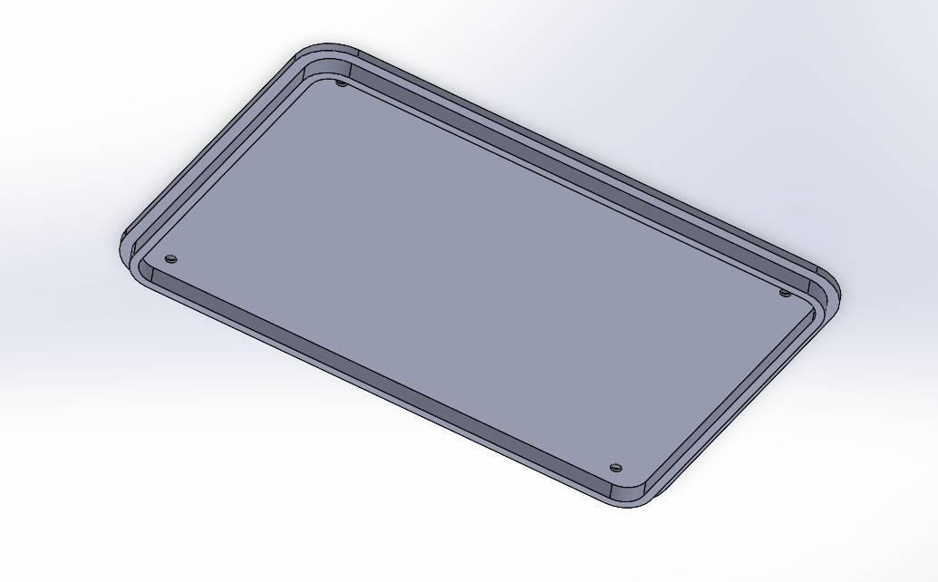
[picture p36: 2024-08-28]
Images/lid 2.png

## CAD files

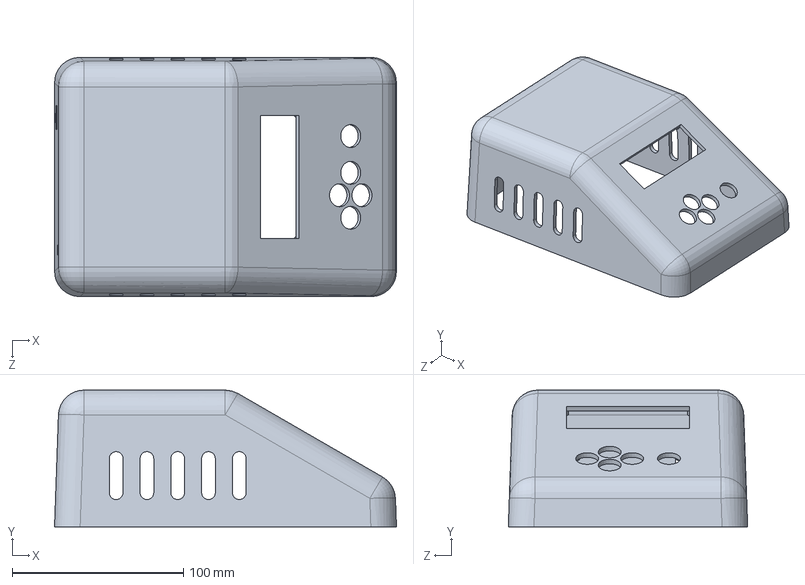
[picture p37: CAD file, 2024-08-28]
Enclosure Designs/top new.SLDPRT
200.0 x 80.0 x 140.0 mm

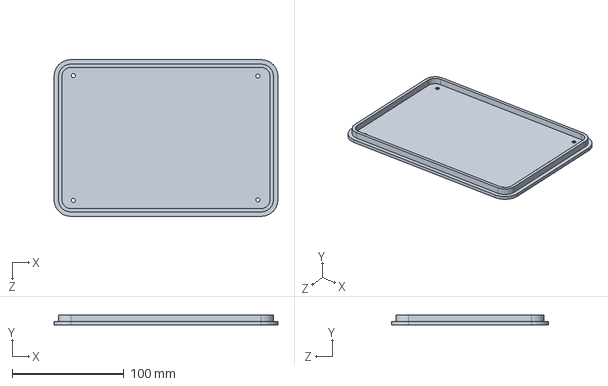
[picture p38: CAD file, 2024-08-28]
Enclosure Designs/base new.SLDPRT
200.0 x 9.00 x 140.0 mm

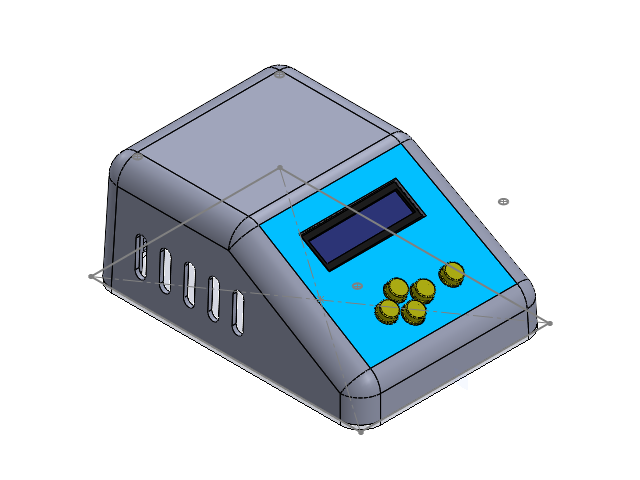
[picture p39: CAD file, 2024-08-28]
Enclosure Designs/Assembly new.SLDASM
top new
lcd 16_2 v3 (1).step
Part42.stp x 5
Part44.stp x 5
Part46.stp x 5
Part52.stp x 5
Part54.stp x 5
Part56.stp x 5
Part58.stp x 5
button-0.stp x 5
pin.stp x 3
Platine.stp
smd-resistor.stp x 6
base new

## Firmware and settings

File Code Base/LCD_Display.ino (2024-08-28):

#include <LiquidCrystal_I2C.h>

#define F_CPU 16000000UL  // 16 MHz clock speed
#include <avr/io.h>
#include <util/delay.h>
#include <avr/interrupt.h>

#define LCD_ADDR 0x27

// LCD address and dimensions
LiquidCrystal_I2C lcd(0x27, 16, 2);

// Potentiometer PIN A1
int Keyboard = A3;

// Variables capturing current and newly calculated position on the letter board
int New_X = 0;
int Old_X = 0;
double Now_time = 0;

bool toggle;

// Variable capturing output from Keyboard pin (Values 0 - 1023)
int Key_read = 0;
int Prev_Key_read = 1023;
boolean Key_pressed = false;

// String variable holding the text to transmit
String To_Transmit = "";

// Used for displaying Letter board
char Letters[] = "EFDMF123456789.";
char* Letters2[] = { "E", "F", "D", "M", "F", "1", "2", "3", "4", "5", "6", "7", "8", "9", "." };

void TWI_init(void);
void TWI_start(void);
void TWI_stop(void);
void TWI_write(uint8_t data);
void lcd_send(uint8_t value, uint8_t mode);
void lcd_command(uint8_t command);
void lcd_data(uint8_t data);
void lcd_init(void);
void lcd_set_cursor(uint8_t row, uint8_t col);
void lcd_print(char* str);

void setup() {
  Serial.begin(9600);

  // // Initialize the LCD
  // lcd.init();
  // lcd.backlight();

  TWI_init();  // Initialize TWI (I2C) and LCD
  lcd_init();

  // Display the initial "OK" indicator
  lcd_set_cursor(14, 0);
  lcd_print("OK");

  // Display the initial "OK" indicator
  lcd_set_cursor(0, 1);
  lcd_print("EFDMF123456789.");

  // Highlight character 'E' by placing a cursor at the first position
  lcd_set_cursor(0, 1);
  // lcd.blink(); // This will make the cursor blink on the selected character
  // lcd_blink_cell(0, 1, "E", 0, 500, 5);

  // delay(1000);

  Now_time = millis();
  toggle = true;
}

void loop() {

  if (millis() - Now_time > 500) {
    if (toggle) {
      lcd_set_cursor(New_X, 1);
      lcd_print(Letters2[New_X]);
    } else {
      lcd_set_cursor(New_X, 1);
      lcd_print(" ");
    }
    toggle = not toggle;
    Now_time = millis();
  }

  Key_read = analogRead(Keyboard);
  Serial.println(Key_read);
  if (Prev_Key_read > 1000 && Key_read < 1000) {
    lcd_set_cursor(0, 1);
    lcd_print("EFDMF123456789.");
    Key_pressed = true;

    // Move left
    if (Key_read > 470 && Key_read < 520 && Old_X > 0) New_X = Old_X - 1;

    // Move right
    if (Key_read < 10 && Old_X < 20) New_X = Old_X + 1;

    // Select character
    if (Key_read > 690 && Key_read < 780) {
      if (New_X != -1) {
        To_Transmit += Letters[New_X];
        lcd_set_cursor(0, 0);
        lcd_print((char*)To_Transmit.c_str());
        lcd_set_cursor(0, 1);
        lcd_print("EFDMF123456789.");
      }
    }

    // Highlight the new letter if cursor moved
    if (Old_X != New_X) {
      // Highlight_letter(New_X, Old_X);
      // lcd_blink_cell(New_X, 1, Letters2[New_X], 0, 500, 1);
      Old_X = New_X;
    }
  }

  Prev_Key_read = Key_read;
}

//////////////////////////////////LCD////////////////////////////

void lcd_blink_cell(uint8_t row, uint8_t col, char* str, uint8_t blink_pos, uint16_t delay_ms, uint8_t blink_count) {
  for (uint8_t i = 0; i < blink_count; i++) {
    // Print the full string with the specified character blank
    lcd_set_cursor(row, col);
    for (uint8_t j = 0; j < strlen(str); j++) {
      if (j == blink_pos) {
        lcd_data(' ');  // Print a blank space at the blink position
      } else {
        lcd_data(str[j]);
      }
    }
    _delay_ms(delay_ms);

    // Print the full string with the original character
    lcd_set_cursor(row, col);
    lcd_print(str);
    _delay_ms(delay_ms);
  }
}


void TWI_init(void) {
  TWSR = 0x00;
  TWBR = 0x48;
  TWCR = (1 << TWEN);  // Enable TWI
}

void TWI_start(void) {
  TWCR = (1 << TWINT) | (1 << TWSTA) | (1 << TWEN);  // Send start condition
  while (!(TWCR & (1 << TWINT)))
    ;  // Wait for TWINT flag
}

void TWI_stop(void) {
  TWCR = (1 << TWINT) | (1 << TWSTO) | (1 << TWEN);  // Send stop condition
  while (TWCR & (1 << TWSTO))
    ;  // Wait for stop to complete
}

void TWI_write(uint8_t data) {
  TWDR = data;                        // Load data into TWDR
  TWCR = (1 << TWINT) | (1 << TWEN);  // Start transmission
  while (!(TWCR & (1 << TWINT)))
    ;  // Wait for TWINT flag
}

void lcd_send(uint8_t value, uint8_t mode) {
  TWI_start();               // Start I2C communication
  TWI_write(LCD_ADDR << 1);  // Write LCD address

  uint8_t data = (value & 0xF0) | mode | 0x08;  // Send upper nibble
  TWI_write(data);
  TWI_write(data | 0x04);  // Pulse the enable bit
  TWI_write(data & ~0x04);

  data = ((value << 4) & 0xF0) | mode | 0x08;  // Send lower nibble
  TWI_write(data);
  TWI_write(data | 0x04);  // Pulse the enable bit
  TWI_write(data & ~0x04);

  TWI_stop();  // Stop I2C communication
}

void lcd_command(uint8_t command) {
  lcd_send(command, 0);
  _delay_ms(2);
}

void lcd_data(uint8_t data) {
  lcd_send(data, 1);
  _delay_ms(2);
}

void lcd_init(void) {
  _delay_ms(50);      // Wait for LCD to power up
  lcd_command(0x02);  // Initialize LCD in 4-bit mode
  lcd_command(0x28);  // Function set: 4-bit mode, 2 lines, 5x8 dots
  lcd_command(0x0C);  // Display on, cursor off
  lcd_command(0x06);  // Entry mode set: Increment cursor
  lcd_command(0x01);  // Clear display
  _delay_ms(2);
}

void lcd_set_cursor(uint8_t col, uint8_t row) {
  uint8_t address = (row == 0) ? 0x80 : 0xC0;
  address += col;
  lcd_command(address);
}

void lcd_print(char* str) {
  while (*str) {
    lcd_data(*str++);
  }
}

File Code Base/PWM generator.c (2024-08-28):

#include <avr/io.h>
#include <util/delay.h>

// Function prototypes
void PWMController_init();
void PWMController_setPWMDutyCycle(uint8_t dutyCycle);
uint8_t PWMController_checkPins();
void PWMController_run();

void PWMController_init() {
	// Set digital pins 0-7 as inputs
	DDRD &= ~0xFF;  // Clear lower 8 bits of DDRD to set PORTD0 to PORTD7 as inputs
	
	// Set digital pin 8 as output (for PWM signal)
	DDRB |= (1 << DDB0);  // Set PORTB0 as output (digital pin 8)

	// Set up Timer0 for PWM
	TCCR0A |= (1 << COM0A1) | (1 << WGM00) | (1 << WGM01);  // Fast PWM mode, non-inverted
	TCCR0B |= (1 << CS01);  // Prescaler set to 8
}

void PWMController_setPWMDutyCycle(uint8_t dutyCycle) {
	OCR0A = (dutyCycle * 255) / 100;  // Set PWM duty cycle
}

uint8_t PWMController_checkPins() {
	for (uint8_t i = 0; i < 8; i++) {
		if (PIND & (1 << i)) {
			return (i + 1) * 10;  // Return duty cycle based on pin level (10%, 20%, ..., 80%)
		}
	}
	return 0;  // If no pins are high, return 0% duty cycle
}

void PWMController_run() {
	while (1) {
		uint8_t dutyCycle = PWMController_checkPins();
		PWMController_setPWMDutyCycle(dutyCycle);
		_delay_ms(100);  // Adjust this value to control the cycle speed
	}
}

int main() {
	PWMController_init();
	PWMController_run();
	return 0;  // This line will never be reached
}
